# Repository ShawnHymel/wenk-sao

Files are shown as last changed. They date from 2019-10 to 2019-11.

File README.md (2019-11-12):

Wenk SAO
========
Wenk Shitty Add-On to be used as a training tool for the "Microcontrollers the Hard Way" workshop. See Documentation/Worksheet and Documentation/Slides for more information.

Solder connector on bottom to use as a Shitty Add-On for badges. Refer to [Shitty Add-On v1.69bis Standard](https://hackaday.io/project/52950-shitty-add-ons/log/159806-introducing-the-shitty-add-on-v169bis-standard) for more information.

VCC: 3.3-5 V
ATtiny84A@1MHz

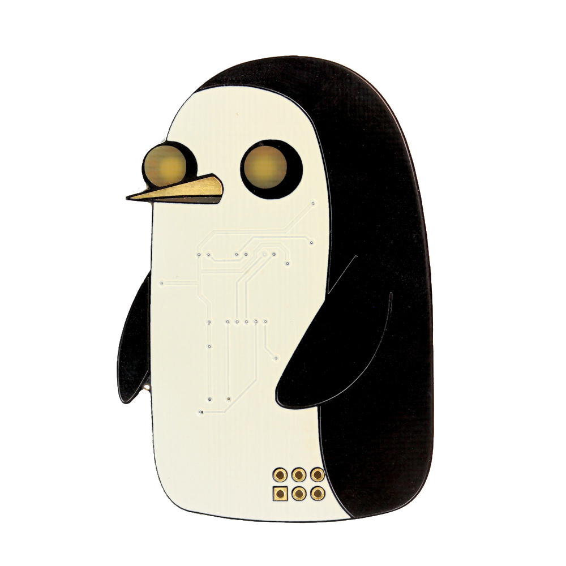
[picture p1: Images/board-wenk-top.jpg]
Wenk Shitty Add-On


Repository Contents
-------------------
* **Documentation** - Slides, worksheet, datasheets
* **Firmware** - Demo programs for the workshop
* **Hardware** - KiCad PCB files, BOM, Gerbers
* **Images** - Photos, diagrams, silkscreen artwork

License
-------
The hardware is released under [Creative Commons Attribution 4.0 International (CC BY 4.0)](https://creativecommons.org/licenses/by/4.0/).

The workshop slides and worksheet are released under [Creative Commons Attribution 4.0 International (CC BY 4.0)](https://creativecommons.org/licenses/by/4.0/).

Demo code in the Firmware directory is [Beerware](https://en.wikipedia.org/wiki/Beerware).

Distributed as-is; no warranty is given.

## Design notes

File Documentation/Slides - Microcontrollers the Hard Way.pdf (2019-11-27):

# Microcontrollers the Hard Way

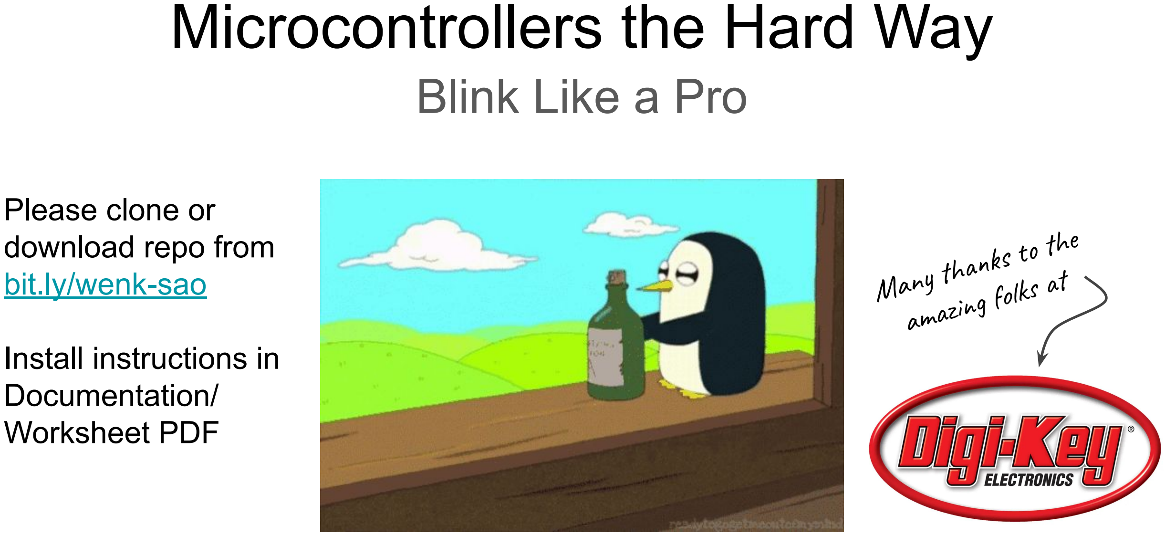
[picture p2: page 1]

# Blink Like a Pro

# Many thanks to the amazing folks at

## Please clone or download repo from bit.ly/wenk-sao

## Install instructions in Documentation/ Worksheet PDF

# Why?

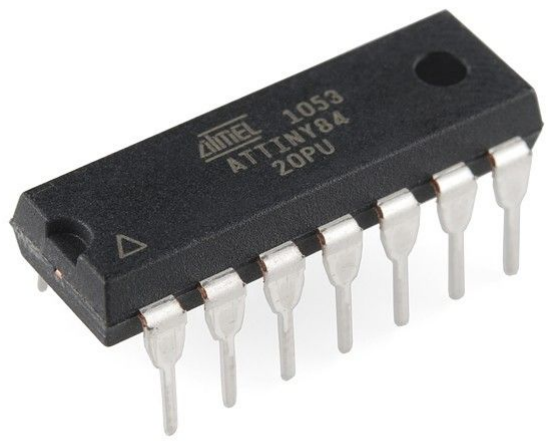
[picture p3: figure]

## - Arduino, Python, MicroPython, CircuitPython are much easier! (Calculator without math) - For product development… - C is usually faster and more space efficient - Need to understand architecture - But AVR is old! 32-bit is the new hotness - Registers - Interrupts - Timers - Peripherals

## Please install AVR toolchain and AVRDUDE while I blab (bit.ly/wenk-sao)

# Hardware Hookup

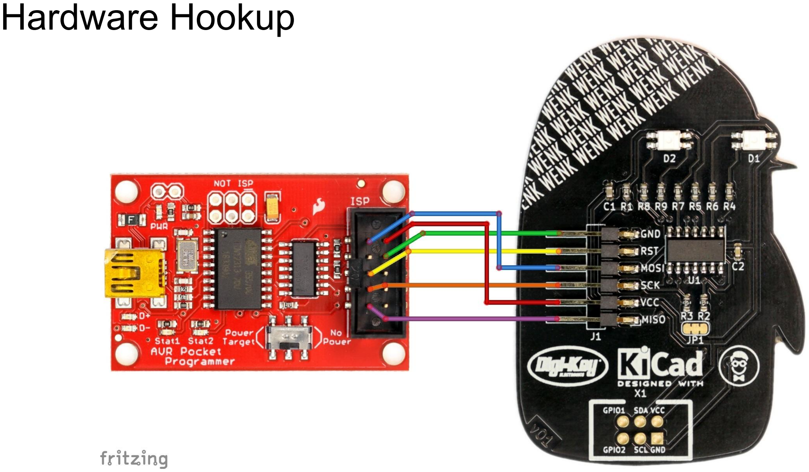
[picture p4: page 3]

# Hints

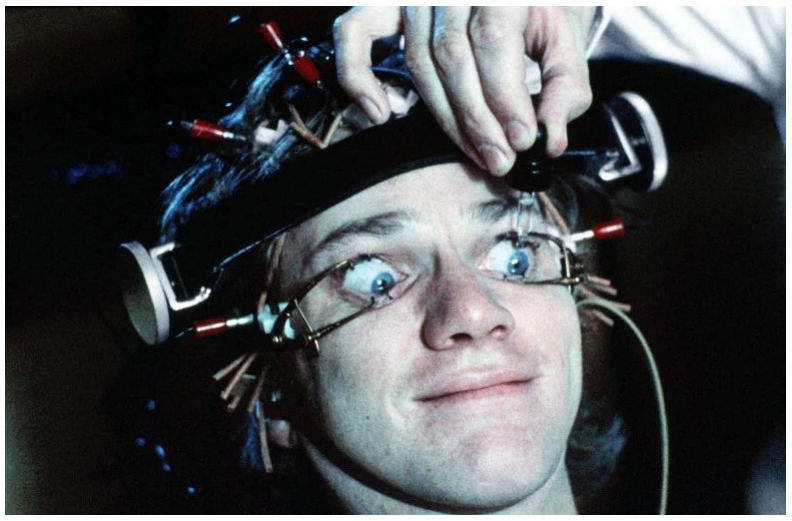
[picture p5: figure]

## - Lots of information ● Type in exercises (at least

## open them from the repo) - Try the challenges ● Have the datasheet open in

## another window

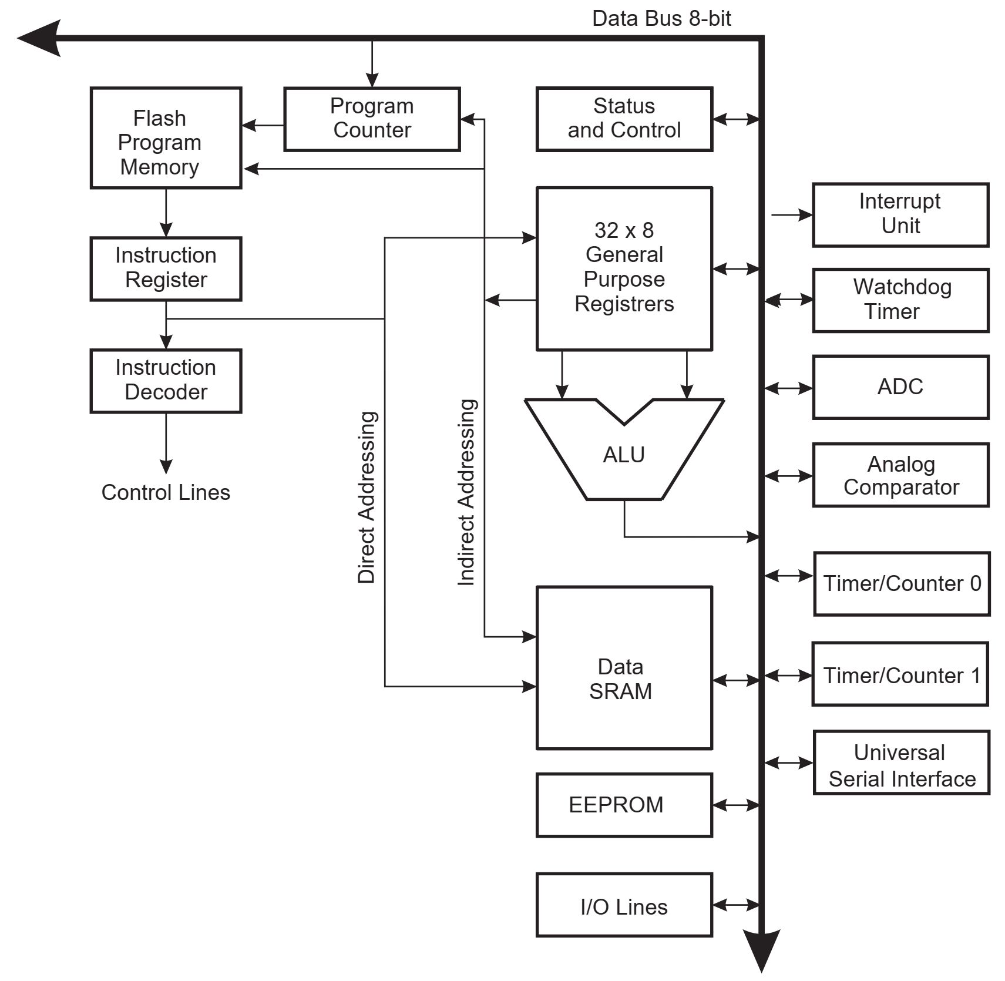
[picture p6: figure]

# ALU

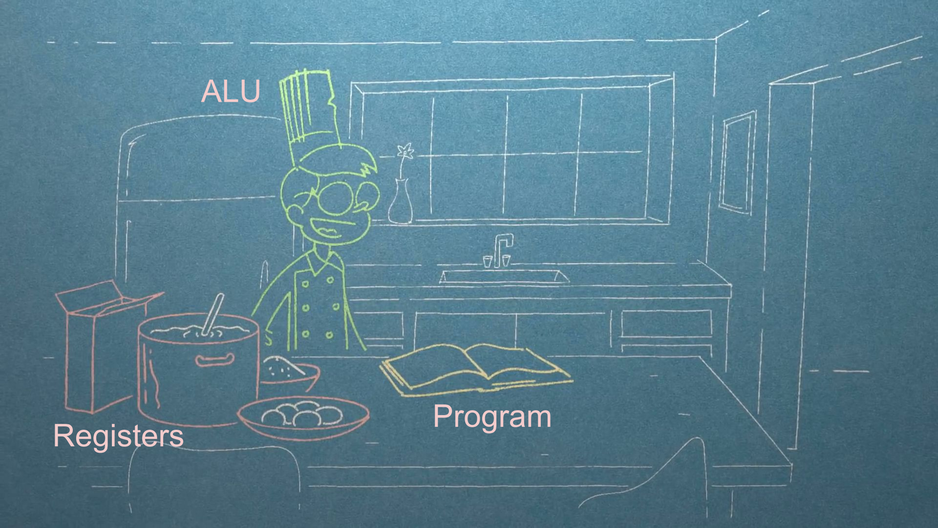
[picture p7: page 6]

Registers | Program

Data Memory

8 bits

32 General
Purpose
Registers

64 I/O Registers

SRAM
(512 x 8 bits)

## Flash (4k x 16 bits)

## Application Flash Section

Program Memory

16 bits

EEPROM

8 bits

EEPROM
(512 x 8 bits)

3 Fuse bytes
1 Lock bytes

Fuses and
Locks
8 bits

Your program lives here

Your variables
live here

Put non-volatile
data here

Danger!
Danger!

## From datasheet

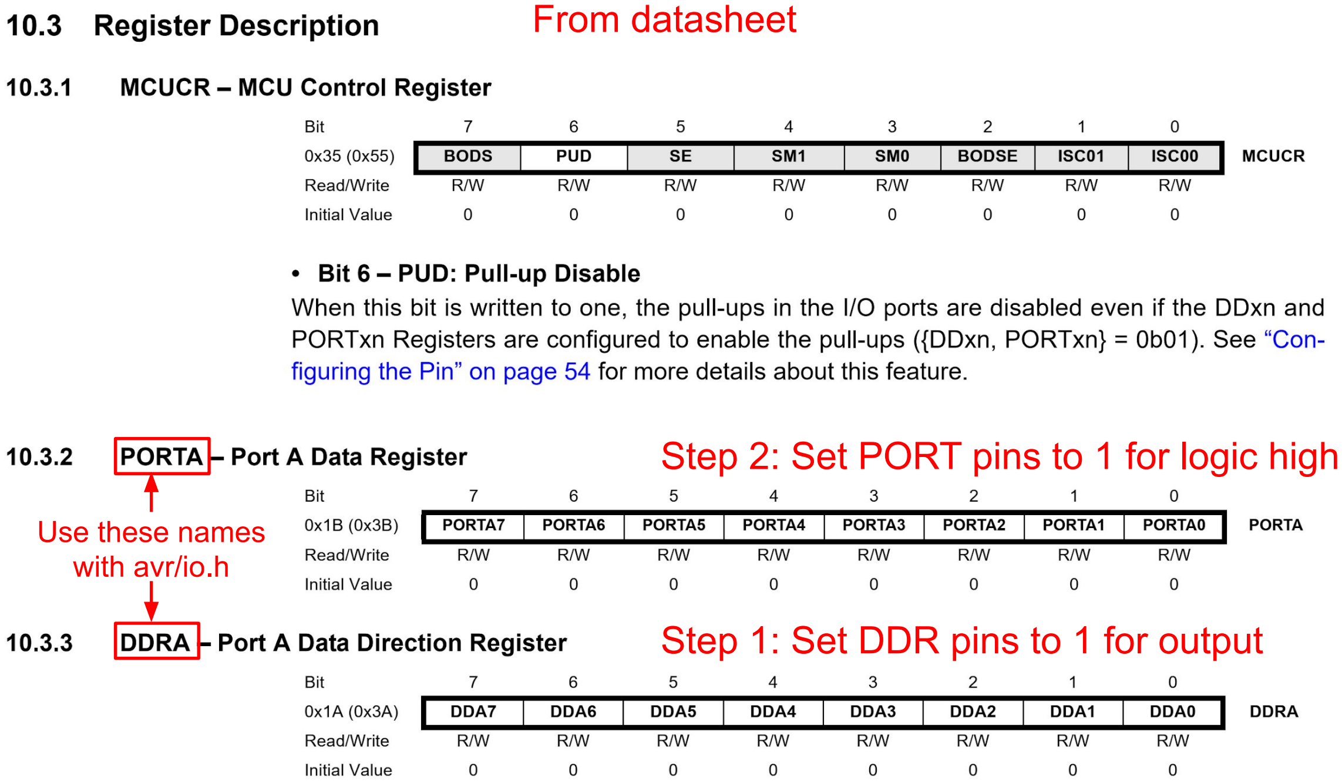
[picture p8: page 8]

## Step 1: Set DDR pins to 1 for output

## Step 2: Set PORT pins to 1 for logic high

Use these names
with avr/io.h

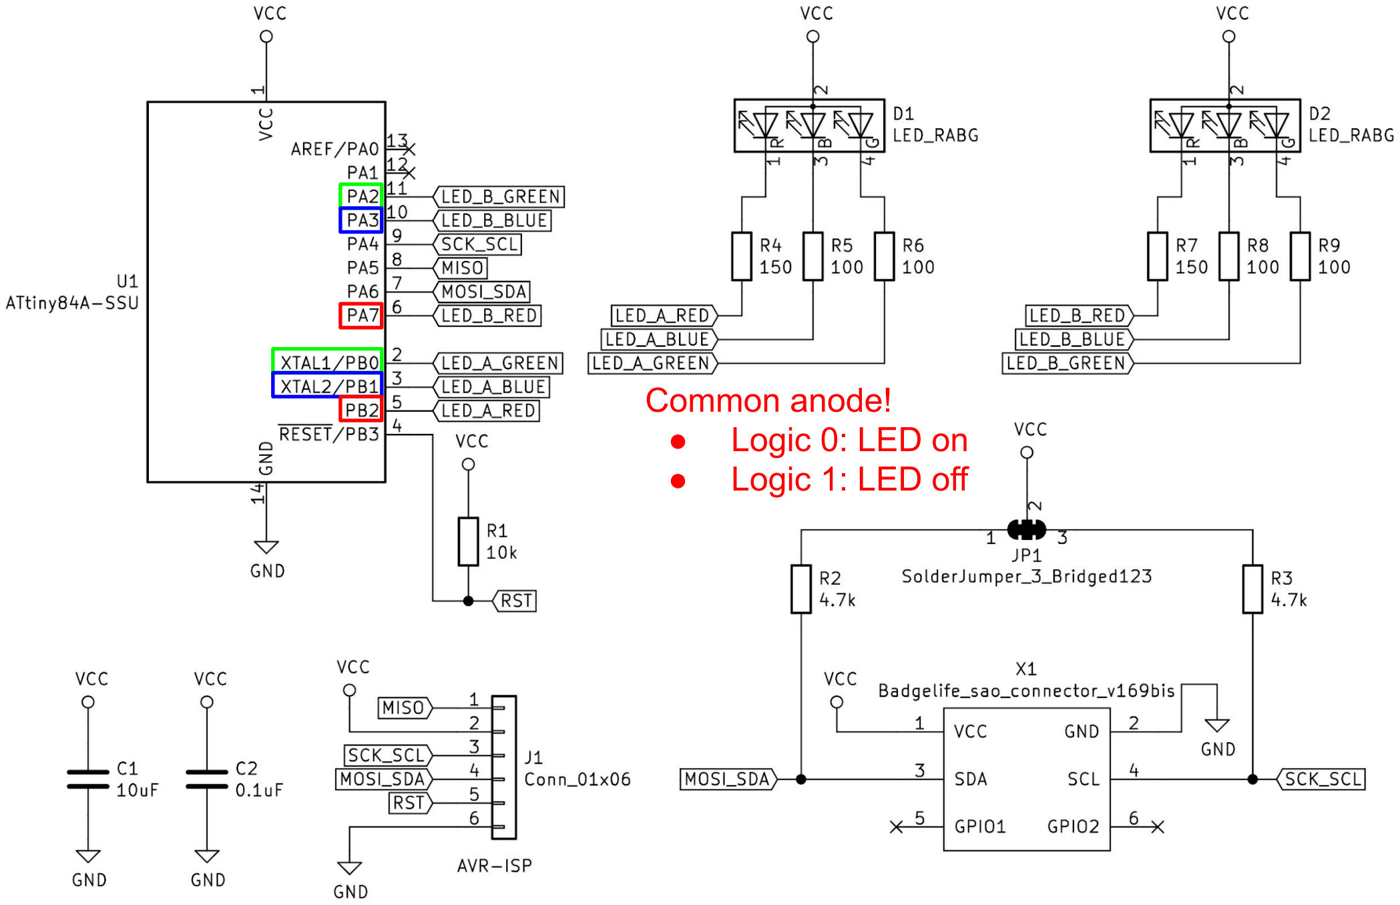
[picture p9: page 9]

Common anode!
- Logic 0: LED on
- Logic 1: LED off

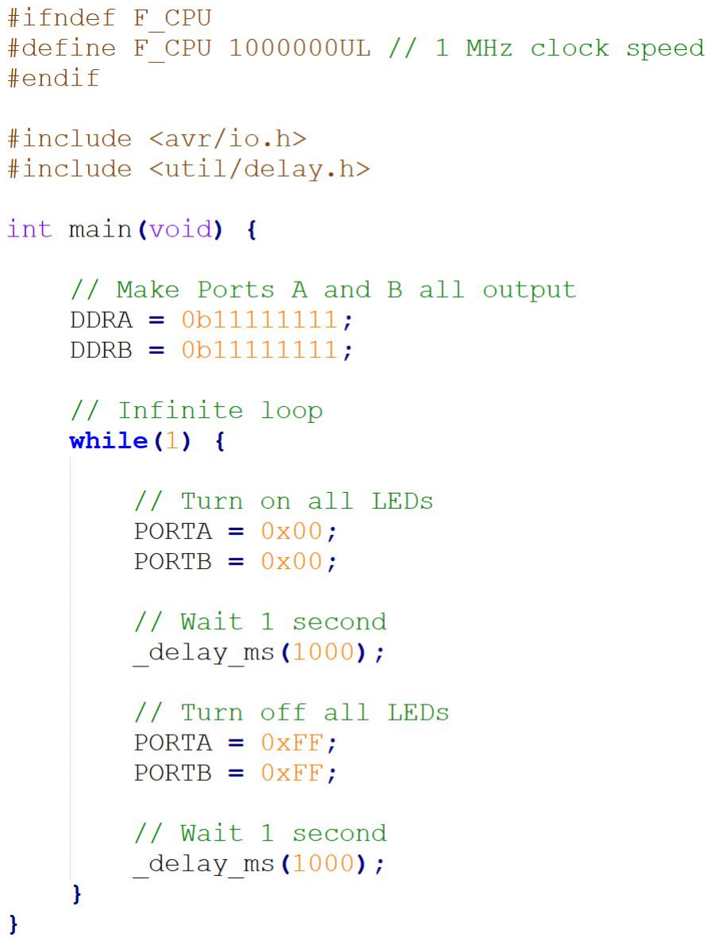
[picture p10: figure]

Exercise 01 - Blinky!

- Create AVR Projects folder somewhere on your computer
- In it, create blinky.c
- In blinky.c, enter the code on the right
- Save
- Open new terminal, enter commands:

avr-gcc -Os -mmcu=attiny84 -o blinky.elf blinky.c avr-objcopy -j .text -j .data -O ihex blinky.elf blinky.hex avrdude -c usbtiny -p t84 -U flash:w:blinky.hex

Or from wenk-sao main directory:

python upload.py <path/to/blinky.c>

Hint: Up arrow is your friend in the terminal to replay commands

Challenge: Only flash the green LED instead of all 3 LEDs

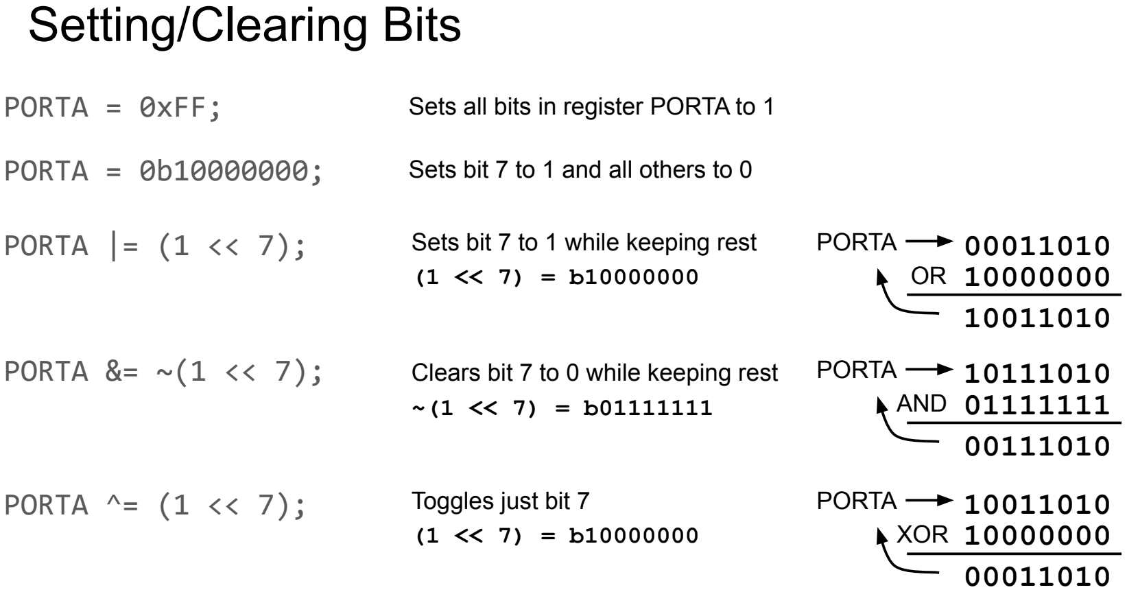
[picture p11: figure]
Setting/Clearing Bits; Sets all bits in register PORTA to 1; Sets bit 7 to 1 and all others to 0; PORTA; Sets bit 7 to 1 while keeping rest; AND 01111111; Clears bit 7 to 0 while keeping rest; XOR 10000000; Toggles just bit 7; PORTA = 0b10000000;; PORTA |= (1 << 7);; PORTA &= ~(1 << 7);; PORTA ^= (1 << 7);; PORTA = 0xFF;

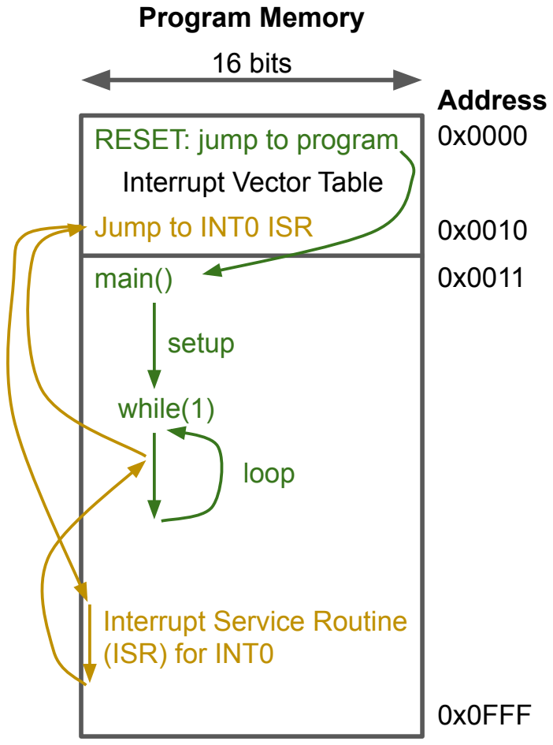
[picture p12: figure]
Program Memory; 16 bits; 0x0FFF; Address; Interrupt Vector Table; RESET: jump to program; main(); while(1); setup; loop; Jump to INT0 ISR; Interrupt Service Routine (ISR) for INT0

# Intro to Interrupts

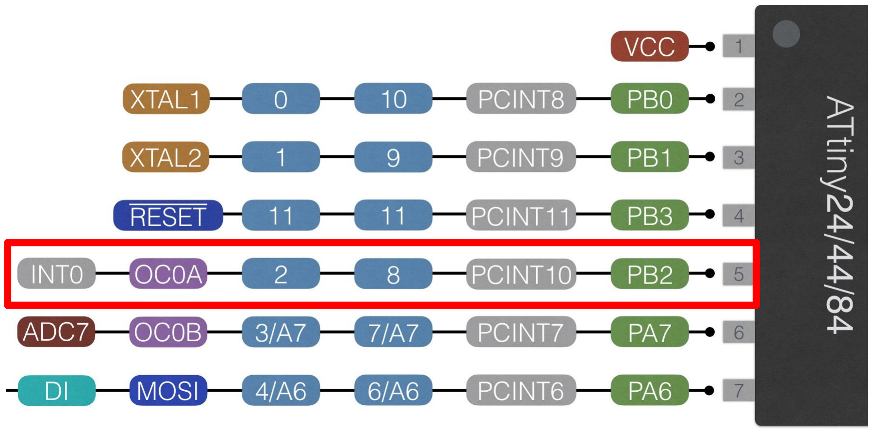
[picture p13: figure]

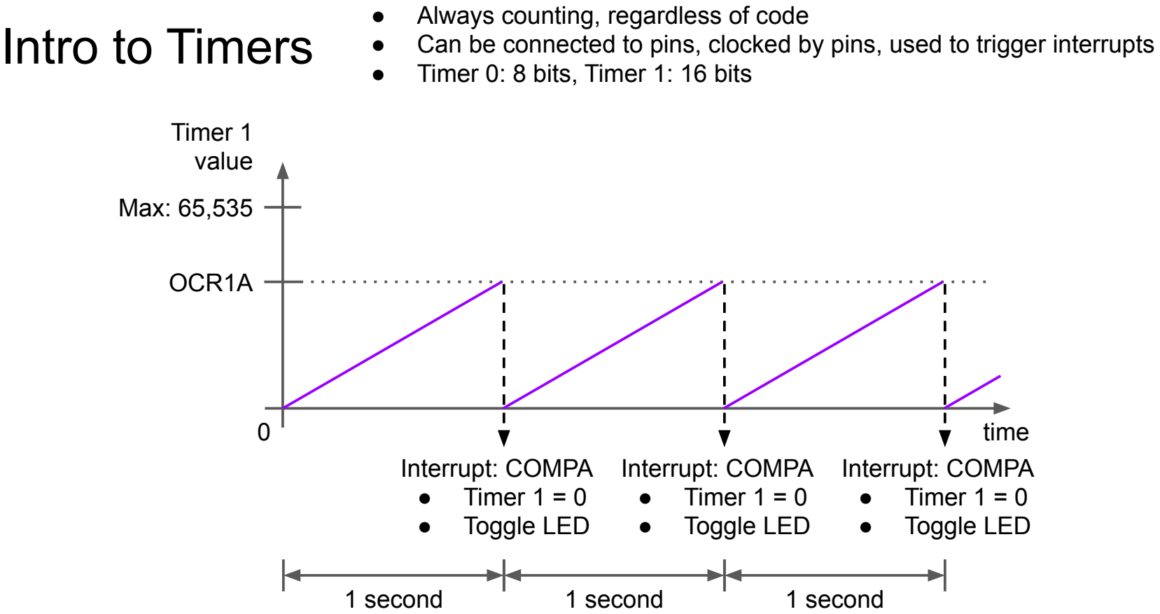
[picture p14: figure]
Intro to Timers; Timer 1 value; Max: 65,535; ● Always counting, regardless of code; ● Timer 0: 8 bits, Timer 1: 16 bits; OCR1A; time; Interrupt: COMPA ● Timer 1 = 0 ● Toggle LED; 1 second

- Can be connected to pins, clocked by pins, used to trigger interrupts

# Timer Calculations

## Period:

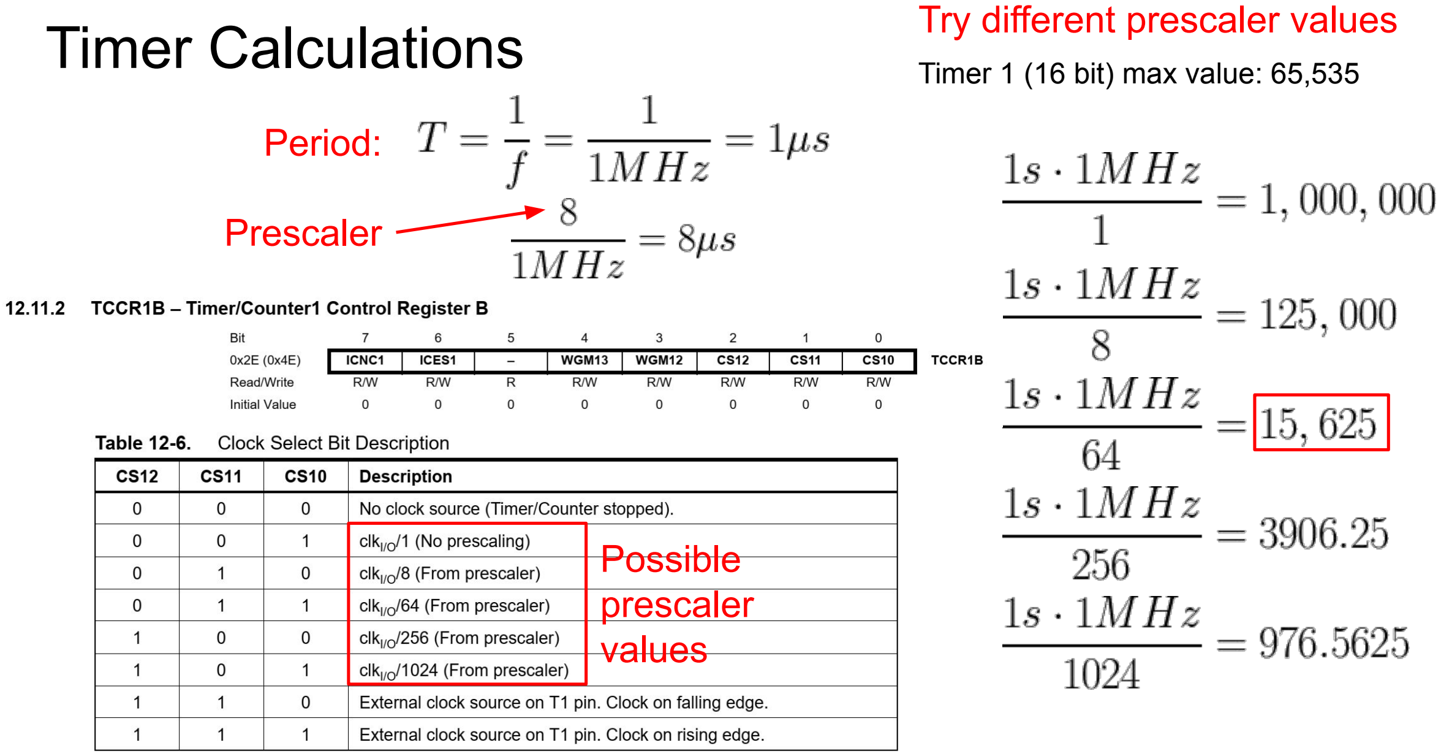
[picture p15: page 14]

## Prescaler

## Possible prescaler values

## Try different prescaler values

Timer 1 (16 bit) max value: 65,535

# How to Set Up Timer 1

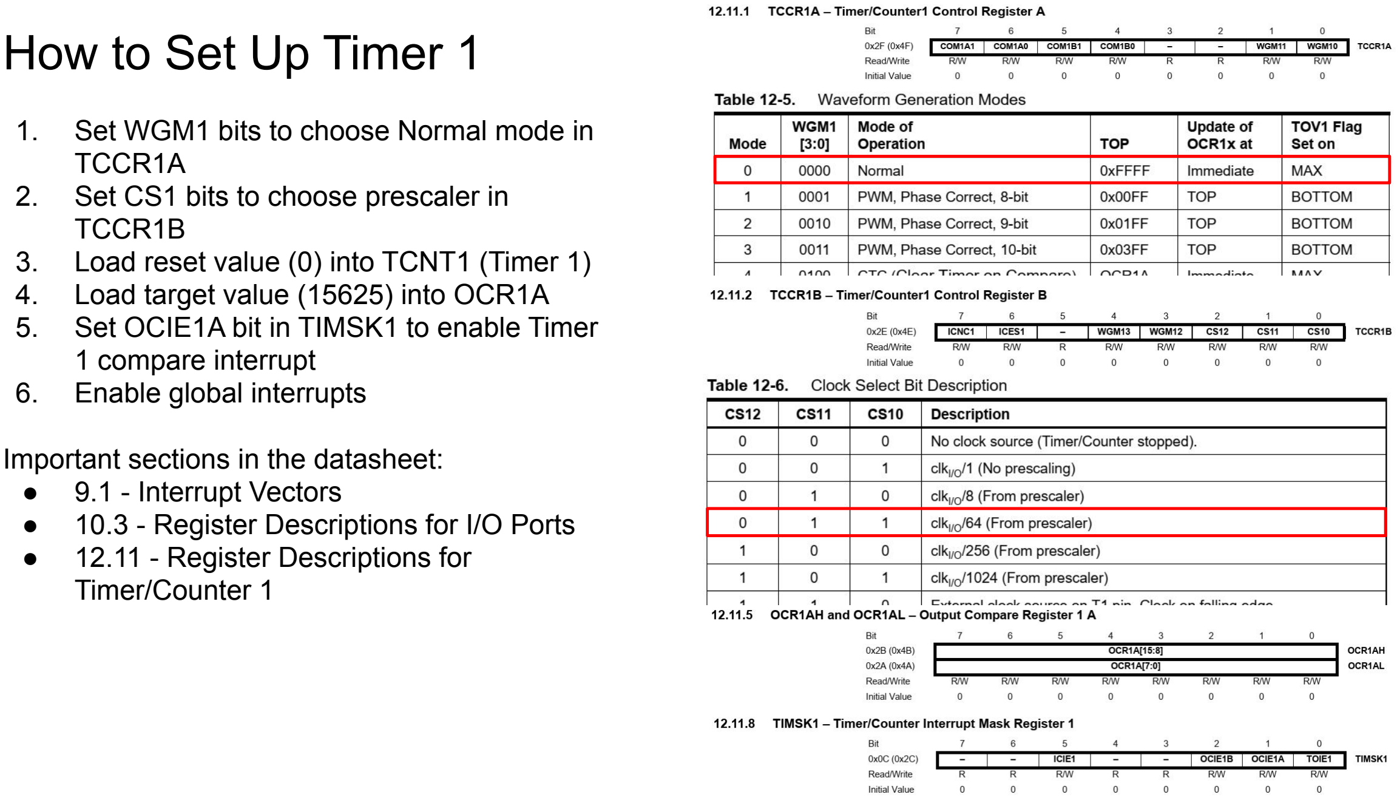
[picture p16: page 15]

1. Set WGM1 bits to choose Normal mode in TCCR1A
2. Set CS1 bits to choose prescaler in TCCR1B
3. Load reset value (0) into TCNT1 (Timer 1)
4. Load target value (15625) into OCR1A
5. Set OCIE1A bit in TIMSK1 to enable Timer 1 compare interrupt
6. Enable global interrupts

Important sections in the datasheet:
- 9.1 - Interrupt Vectors
- 10.3 - Register Descriptions for I/O Ports
- 12.11 - Register Descriptions for Timer/Counter 1

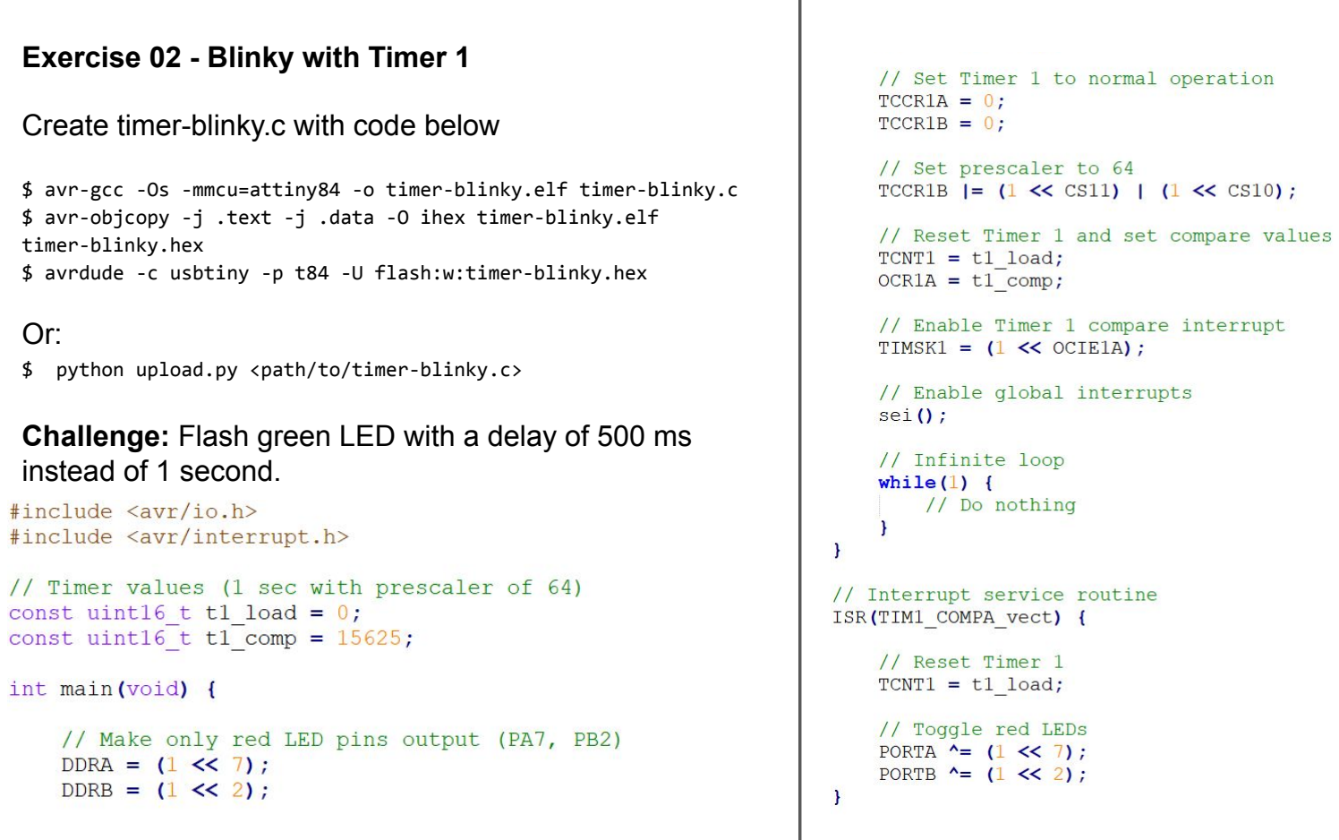
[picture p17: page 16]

Exercise 02 - Blinky with Timer 1

Create timer-blinky.c with code below

$ avr-gcc -Os -mmcu=attiny84 -o timer-blinky.elf timer-blinky.c $ avr-objcopy -j .text -j .data -O ihex timer-blinky.elf timer-blinky.hex
$ avrdude -c usbtiny -p t84 -U flash:w:timer-blinky.hex

Or:

$ python upload.py <path/to/timer-blinky.c>

Challenge: Flash green LED with a delay of 500 ms instead of 1 second.

# Intro to Pulse Width Modulation

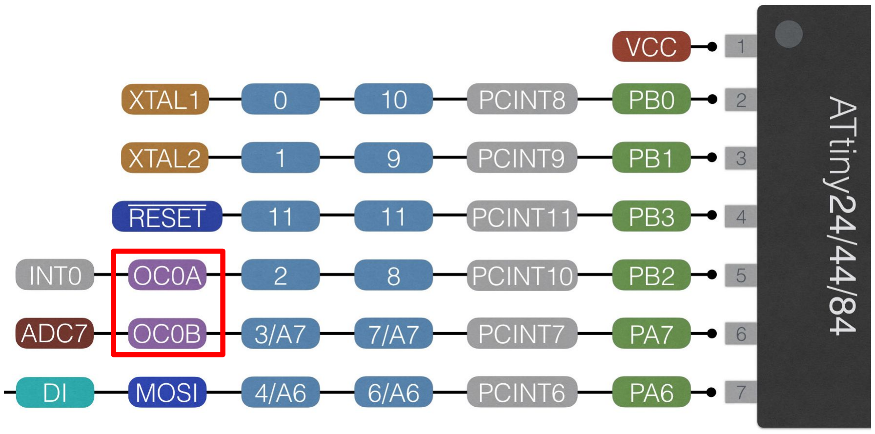
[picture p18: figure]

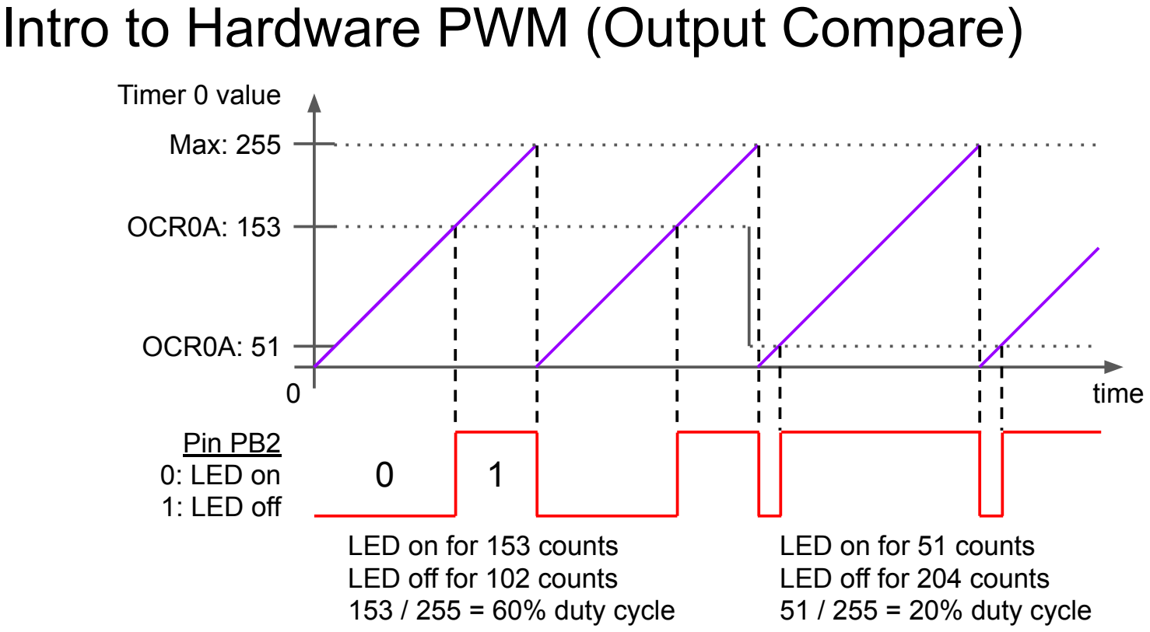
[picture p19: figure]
Intro to Hardware PWM (Output Compare); Timer 0 value; Max: 255; OCR0A: 153; time; Pin PB2 0: LED on 1: LED off; LED on for 153 counts LED off for 102 counts 153 / 255 = 60% duty cycle; OCR0A: 51; LED on for 51 counts LED off for 204 counts 51 / 255 = 20% duty cycle

# How to Set Up PWM

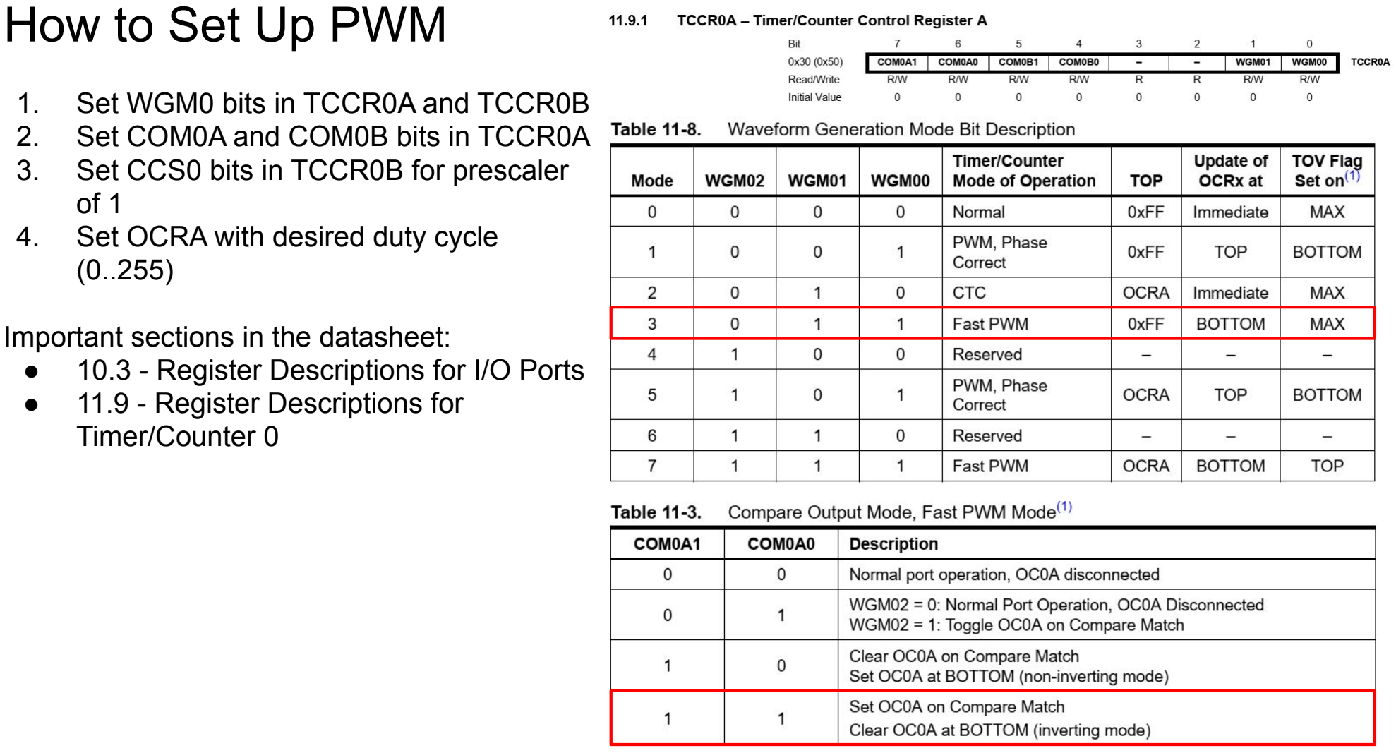
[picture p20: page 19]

1. Set WGM0 bits in TCCR0A and TCCR0B
2. Set COM0A and COM0B bits in TCCR0A
3. Set CCS0 bits in TCCR0B for prescaler of 1
4. Set OCRA with desired duty cycle (0..255)

Important sections in the datasheet:
- 10.3 - Register Descriptions for I/O Ports
- 11.9 - Register Descriptions for Timer/Counter 0

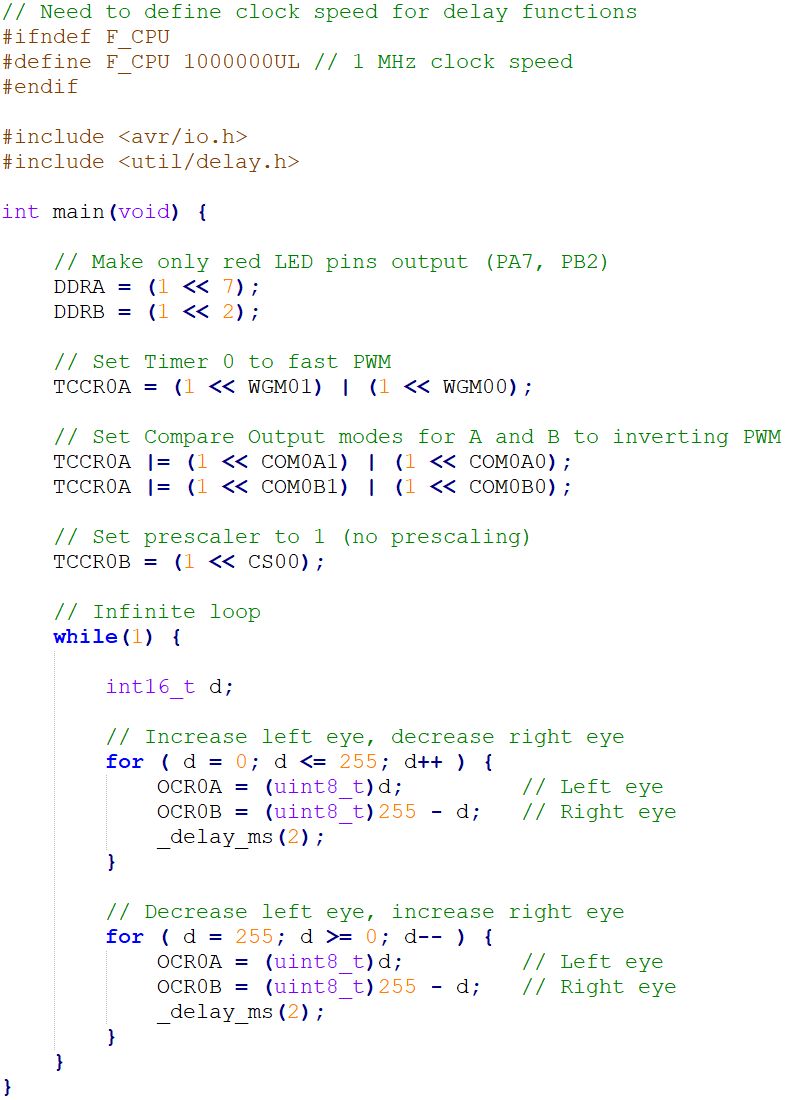
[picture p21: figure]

Exercise 03 - Hardware PWM

Create hardware-pwm.c with code to the right

$ avr-gcc -Os -mmcu=attiny84 -o hardware-pwm.elf hardware-pwm.c $ avr-objcopy -j .text -j .data -O ihex hardware-pwm.elf hardware-pwm.hex
$ avrdude -c usbtiny -p t84 -U flash:w:hardware-pwm.hex

Or:

$ python upload.py <path/to/hardware-pwm.c>

Challenge: Notice that a duty cycle of 0% does not completely turn off LED. This is because in Fast PWM mode, at least 1 clock cycle happens while pin is low (LED on). Fix this by using Phase Correct PWM.

Hint: Read about the WGM0 bits in the TCCR0A register (datasheet section 11.9.1)

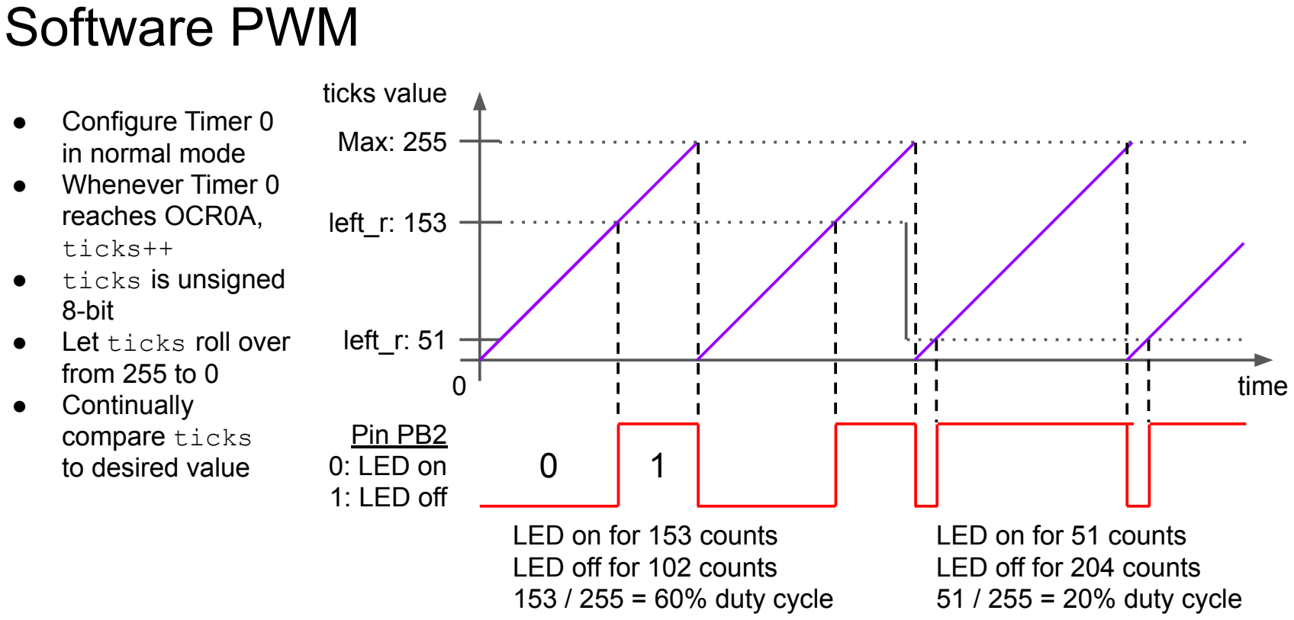
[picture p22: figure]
Software PWM; ticks value; Max: 255; left_r: 153; time; Pin PB2 0: LED on 1: LED off; LED on for 153 counts LED off for 102 counts 153 / 255 = 60% duty cycle; left_r: 51; LED on for 51 counts LED off for 204 counts 51 / 255 = 20% duty cycle; ● Configure Timer 0 in normal mode ● Whenever Timer 0 reaches OCR0A,; ticks++ ● ticks is unsigned 8-bit ● Let ticks roll over from 255 to 0 ● Continually compare ticks to desired value

# PWM Frequency

## CPU clock: 1 MHz

## Timer 0 prescaler: 1

## OCR0A (comp): ???

## Ticks counting from 0 to 255 is one period

## 50 Hz LED refresh looks decent (and it’s the best we can do)

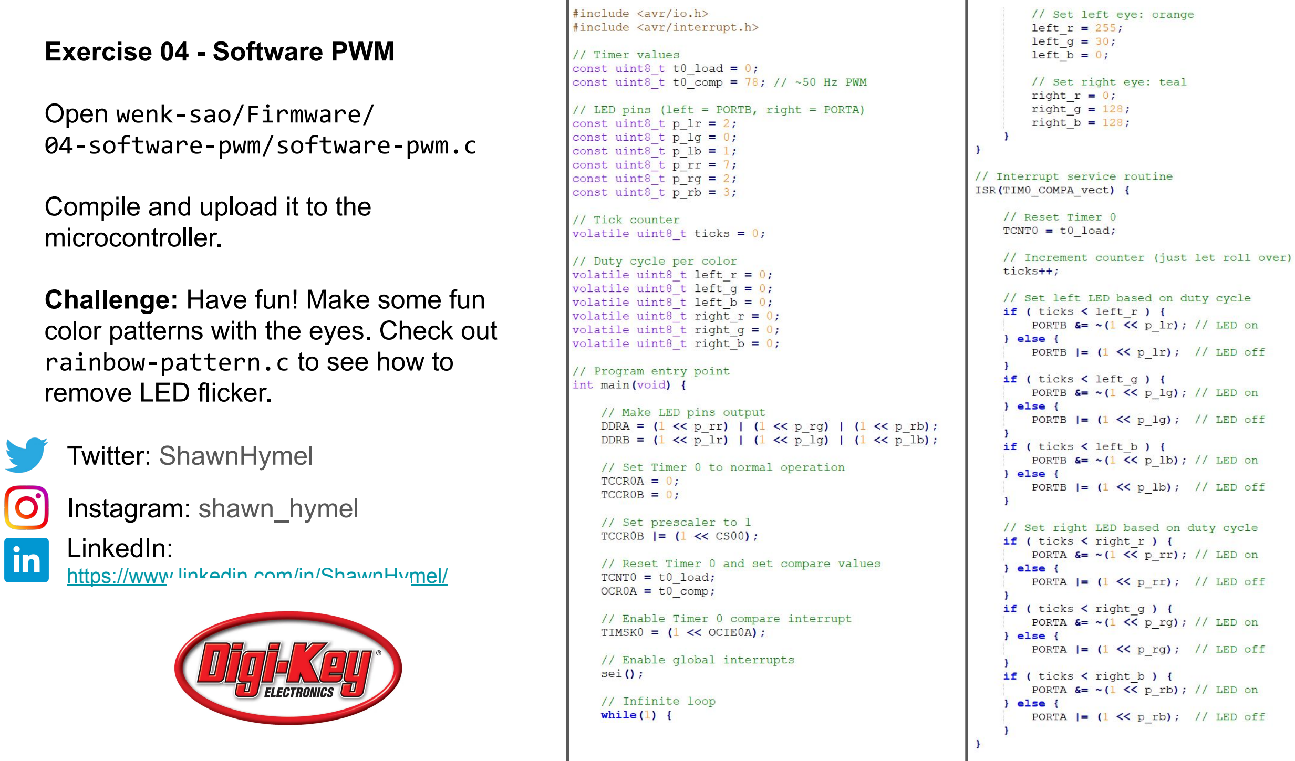
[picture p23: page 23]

Exercise 04 - Software PWM

Open wenk-sao/Firmware/
04-software-pwm/software-pwm.c

Compile and upload it to the microcontroller.

Challenge: Have fun! Make some fun color patterns with the eyes. Check out rainbow-pattern.c to see how to remove LED flicker.

Twitter: ShawnHymel

Instagram: shawn_hymel
LinkedIn:
https://www.linkedin.com/in/ShawnHymel/

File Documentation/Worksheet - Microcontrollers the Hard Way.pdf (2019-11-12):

## Microcontrollers the Hard Way

Worksheet by Shawn Hymel (License: CC BY 4.0) Presented by DigiKey Electronics

Name:______________________ Date:_______________________

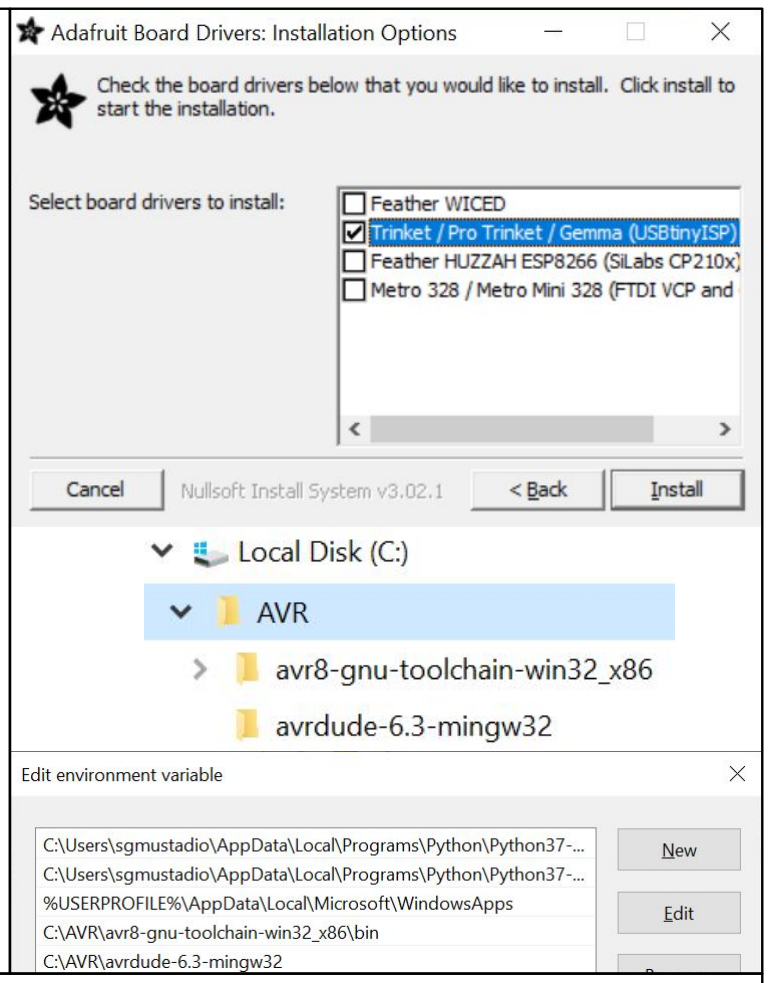
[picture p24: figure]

Installation (Windows)
- Install driver: bit.ly/adafruit-drivers-install
- Select Trinket…(USBtinyISP)
- Now plug in AVR Programmer
- Create folder C:\AVR
- Download AVR 8-bit Toolchain for Windows (v3.62) from: bit.ly/avr-toolchain-install
- Unzip into C:\AVR
- Download avrdude-6.3-mingw32.zip from: http://bit.ly/avrdude-install
- Unzip into C:\AVR\avrdude-6.3-mingw32
- Update Path
- Control Panel > System and Security > System > Advanced System Settings > Advanced tab > Environment Variables
- User Variables, select Path, click Edit
- Click New, Click Browse…, add C:\AVR\avr8-gnu-toolchain-win32_x86\bin
- Click New, Click Browse…, add C:\AVR\avrdude-6.3-mingw32

Toolchain Setup

Installation (Mac)
- Install Homebrew:
$ ruby -e "$(curl -fsSL https://raw.githubusercontent.com/Homebrew/install/master/install)"
- Install AVR toolchain:
$ brew tap osx-cross/avr
$ brew install avr-gcc
- Install avrdude:
$ brew install avrdude

Installation (Linux)
- Install AVR toolchain and avrdude:
$ sudo apt update
$ sudo apt install -y gcc-avr binutils-avr avr-libc avrdude
- Download ZIP from github.com/ShawnHymel/wenk-sao
- Unzip somewhere on your computer

Project Files

- In a terminal, enter $ avr-gcc
- You should see an error: avr-gcc: fatal error: no input files
- Next, enter $ avrdude
- You should see an error: Usage: avrdude [options]

Test It!

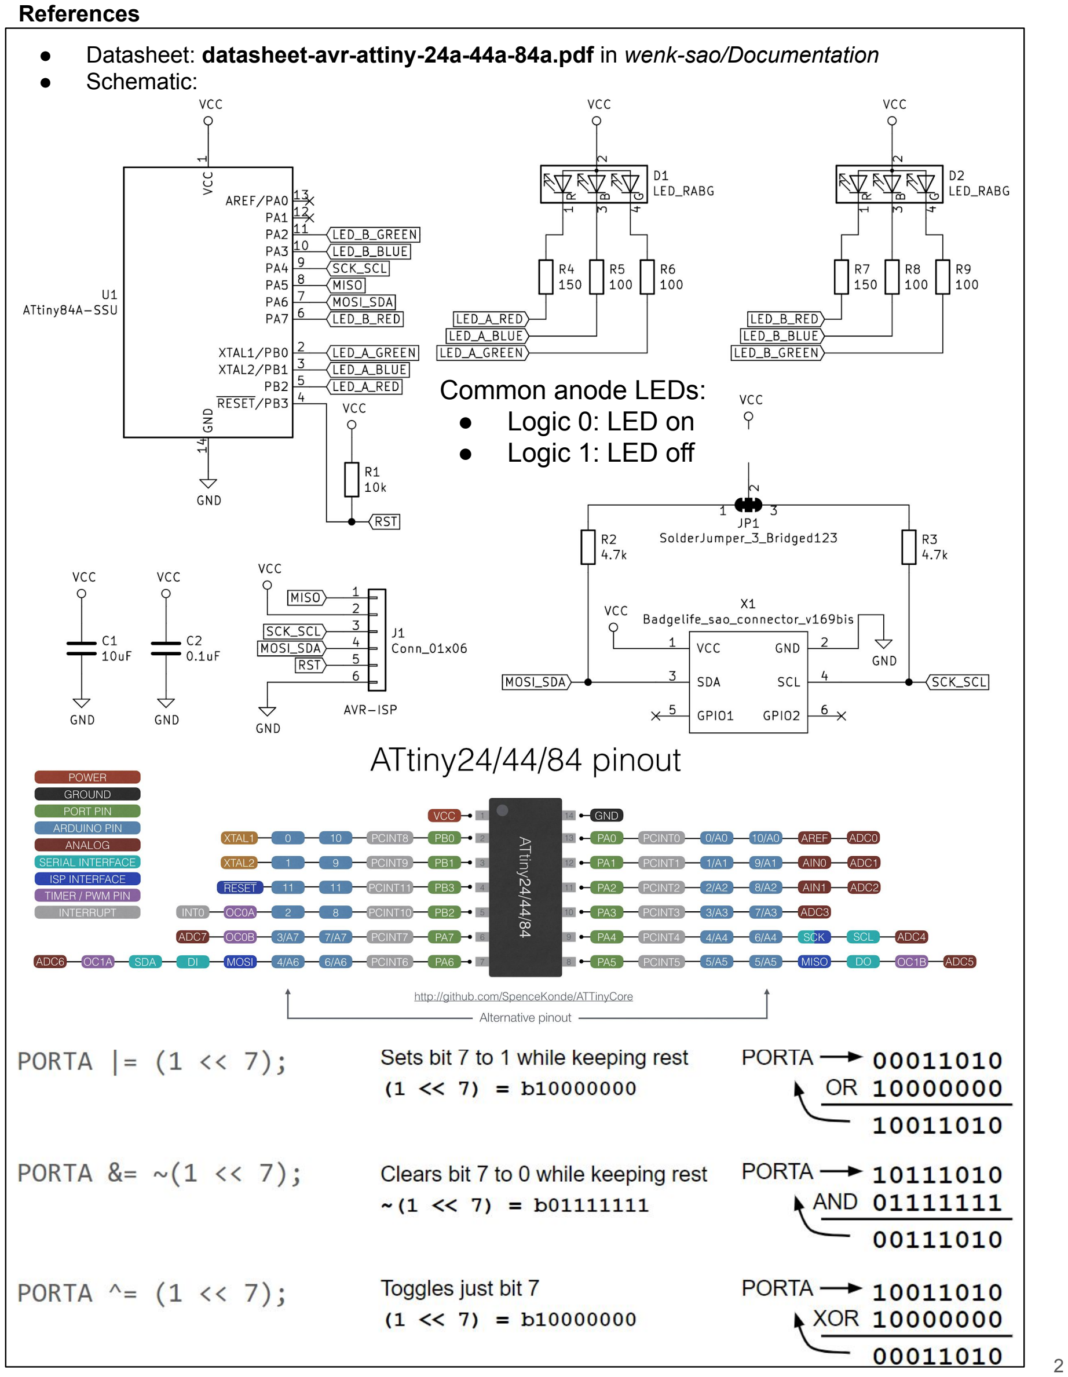
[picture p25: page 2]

- Datasheet: datasheet-avr-attiny-24a-44a-84a.pdf in wenk-sao/Documentation
- Schematic:

References

Common anode LEDs:
- Logic 0: LED on
- Logic 1: LED off


Hardware Connections

Exercise 01 - Blinky!


Compile and Upload
Open new terminal, enter commands:
$ cd <location of your AVR Projects directory>
$ avr-gcc -Os -mmcu=attiny84 -o blinky.elf blinky.c
$ avr-objcopy -j .text -j .data -O ihex blinky.elf blinky.hex $ avrdude -c usbtiny -p t84 -U flash:w:blinky.hex

Or if you have Python (from wenk-sao directory):
$ python upload.py <path/to/blinky.c>

Hint: up arrow is your friend in the terminal to replay commands

Challenge: Flash only the green LED instead of all 3 LEDs

Write Code
- Create AVR Projects folder somewhere on your computer
- In it, create blinky.c
- Open blinky.c with your favorite editor (not WordPad)
- In blinky.c, enter the code on the right
- Save

Exercise 02 - Blinky with Timer 1

Compile and Upload


$ avr-gcc -Os -mmcu=attiny84 -o timer-blinky.elf timer-blinky.c
$ avr-objcopy -j .text -j .data -O ihex timer-blinky.elf timer-blinky.hex $ avrdude -c usbtiny -p t84 -U flash:w:timer-blinky.hex

Or if you have Python (from wenk-sao directory):
$ python upload.py <path/to/timer-blinky.c>

Challenge: Flash green LED with a delay of 500 ms instead of 1 second.

Write Code
- Create timer-blinky.c
- Open timer-blinky.c with your favorite editor (not WordPad)
- In timer-blinky.c, enter the code on the right
- Save

Important Datasheet Sections
- 9.1 - Interrupt Vectors
- 10.3 - Register Descriptions for I/O Ports
- 12.11 - Register Descriptions for Timer/Counter 1

Exercise 03 - Hardware PWM

Compile and Upload


$ avr-gcc -Os -mmcu=attiny84 -o hardware-pwm.elf hardware-pwm.c
$ avr-objcopy -j .text -j .data -O ihex hardware-pwm.elf hardware-pwm.hex $ avrdude -c usbtiny -p t84 -U flash:w:hardware-pwm.hex

Or if you have Python (from wenk-sao directory):
$ python upload.py <path/to/hardware-pwm.c>

Challenge: Notice that a duty cycle of 0% does not completely turn off LED. This is because in Fast PWM mode, at least 1 clock cycle happens while pin is low (LED on). Fix this by using Phase Correct PWM.

Hint: Read about the WGM0 bits in the TCCR0A register (datasheet section 11.9.1)

Write Code
- Create hardware-pwm.c
- Open hardware-pwm.c with your favorite editor (not WordPad)
- In hardware-pwm.c, enter the code on the right
- Save

Important Datasheet Sections
- 10.3 - Register Descriptions for I/O Ports
- 11.9 - Register Descriptions for Timer/Counter 0

Exercise 04 - Software PWM

This is more for fun! Open wenk-sao/Firmware/04-software-pwm/software-pwm.c and play around with it.

Compile and Upload
$ avr-gcc -Os -mmcu=attiny84 -o software-pwm.elf software-pwm.c
$ avr-objcopy -j .text -j .data -O ihex software-pwm.elf software-pwm.hex $ avrdude -c usbtiny -p t84 -U flash:w:software-pwm.hex

Or if you have Python (from wenk-sao directory):
$ python upload.py <path/to/software-pwm.c>

Challenge: Make some fun color patterns with the eyes. Check out rainbow-pattern.c to see how to remove LED flicker.

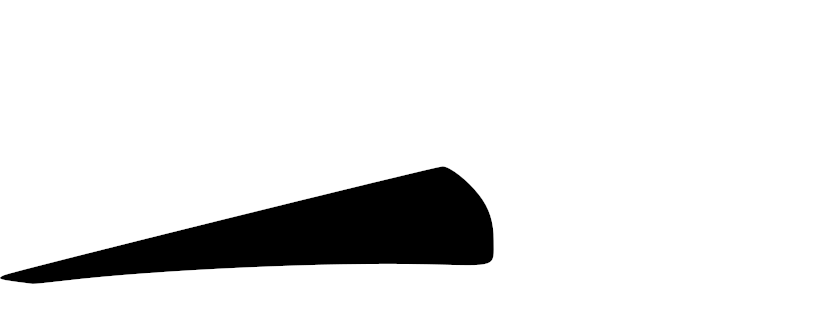
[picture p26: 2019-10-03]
Images/gunter-exposed_copper.png

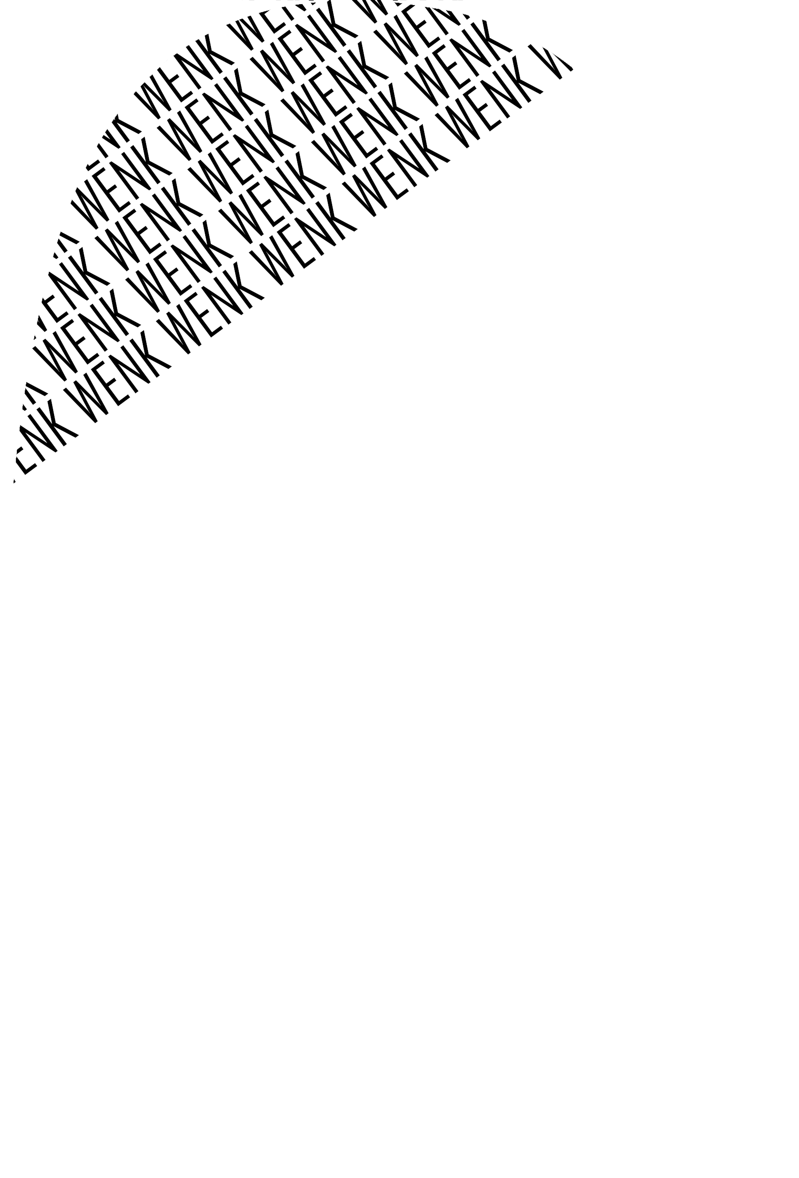
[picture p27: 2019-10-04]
Images/gunter-back_silk.png

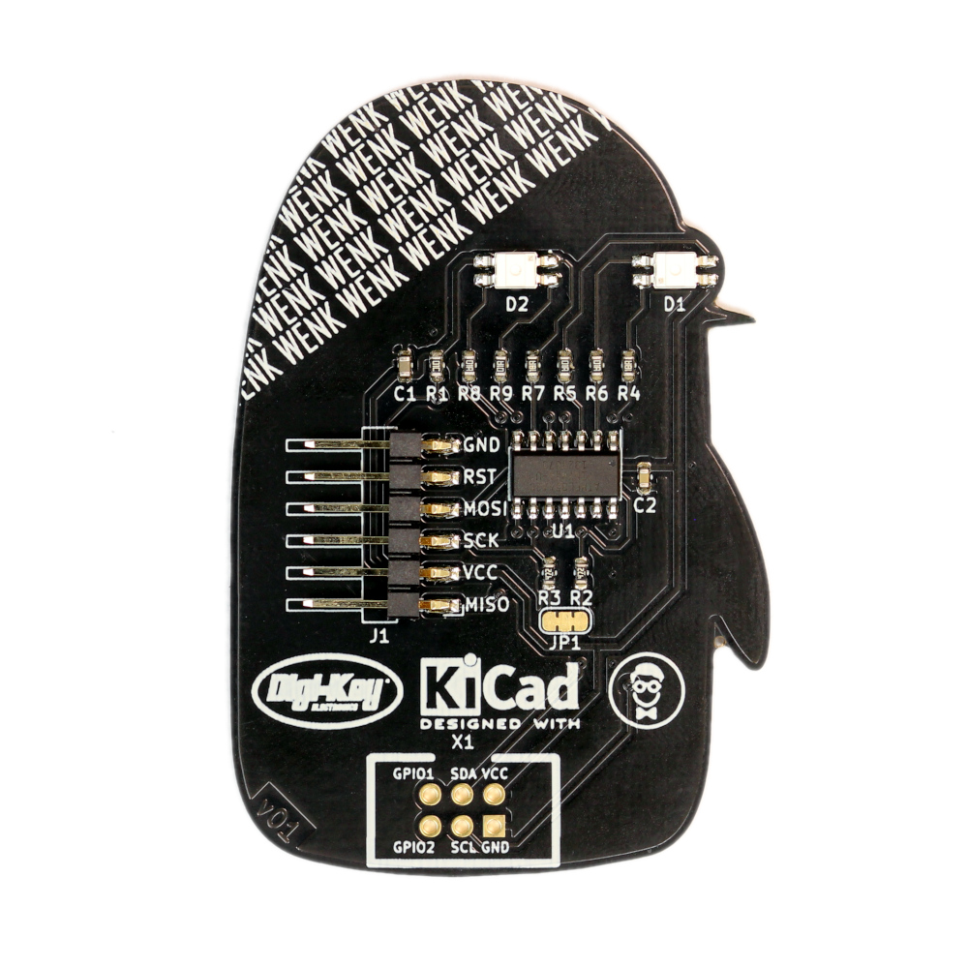
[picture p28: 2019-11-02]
Images/board-wenk-bottom.jpg

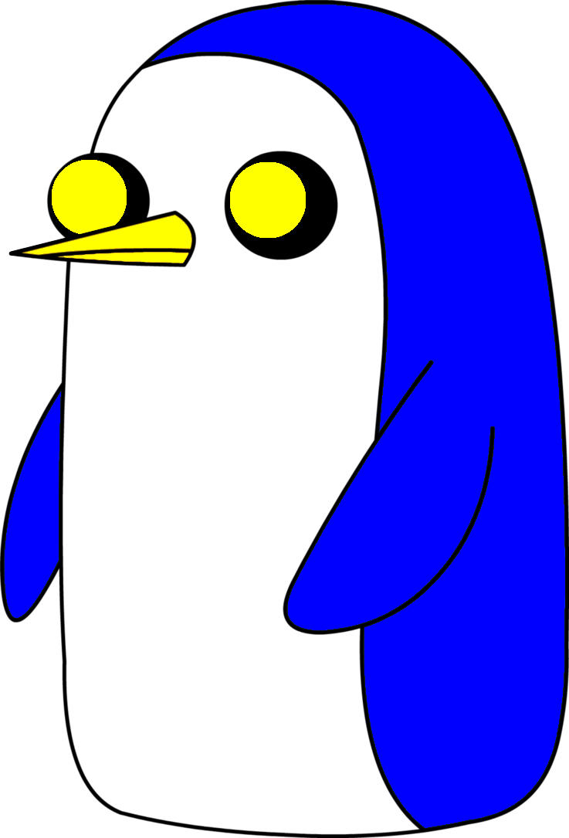
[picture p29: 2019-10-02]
Images/gunter-layers.png

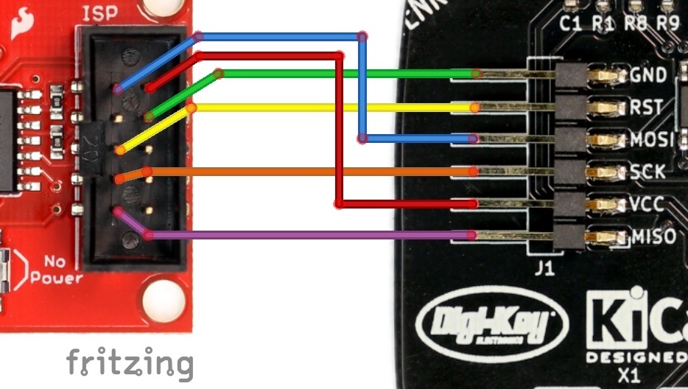
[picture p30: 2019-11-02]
Images/programmer-hookup_bb_cropped.jpg

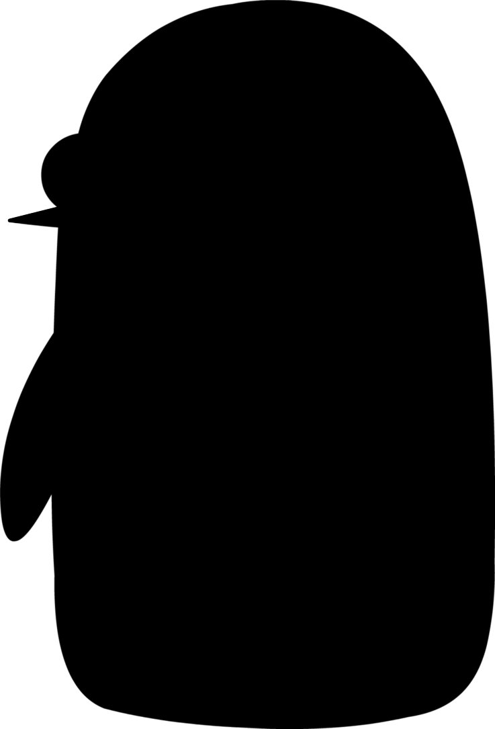
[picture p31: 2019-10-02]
Images/gunter-black.png

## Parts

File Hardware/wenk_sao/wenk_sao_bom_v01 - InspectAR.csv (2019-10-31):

Component | Description | Part | RefDes | Value | Footprint | Quantity Per PCB | Datasheet | MPN
1 | Unpolarized capacitor | C | C2 | 0.1uF | C_0603_1608Metric | 1 | ~ | 1276-1000-1-ND
2 | Unpolarized capacitor | C | C1 | 10uF | C_0603_1608Metric | 1 | ~ | 1276-1119-1-ND
3 | RGB LED, anode/red/green/blue | LED_RABG | D1 D2 | LED_RABG | XZMDKCBDDG45S-9 | 2 | ~ | 1497-1257-1-ND
4 | Generic connector, single row, 01x06, script generated (kicad-library-utils/schlib/autogen/connector/) | Conn_01x06 | J1 | Conn_01x06 | Harwin_M20-89006xx_1x06_P2.54mm_Horizontal | 1 | ~ | 952-3235-ND
5 | Resistor | R | R5 R6 R8 R9 | 100 | R_0603_1608Metric | 4 | ~ | 311-100HRCT-ND
6 | Resistor | R | R1 | 10k | R_0603_1608Metric | 1 | ~ | 311-10.0KHRCT-ND
7 | Resistor | R | R4 R7 | 150 | R_0603_1608Metric | 2 | ~ | 311-150HRCT-ND
8 | Resistor | R | R2 R3 | 4.7k | R_0603_1608Metric | 2 | ~ | 311-4.70KHRCT-ND
9 | 20MHz, 8kB Flash, 512B SRAM, 512B EEPROM, debugWIRE, SOIC-14 | ATtiny84A-SSU | U1 | ATtiny84A-SSU | SOIC-14_3.9x8.7mm_P1.27mm | 1 | http://ww1.microchip.com/downloads/en/DeviceDoc/doc8183.pdf | ATTINY84A-SSURCT-ND
10 |  | Badgelife_sao_connector_v169bis | X1 | Badgelife_sao_connector_v169bis | Badgelife-SAOv169-SAO-2x3_nopin1 | 1 |  | 732-5394-ND

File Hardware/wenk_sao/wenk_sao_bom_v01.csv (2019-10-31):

Component | Description | Part | References | Value | Footprint | Quantity Per PCB | Datasheet | Digi-Key_PN
1 | Unpolarized capacitor | C | C2 | 0.1uF | C_0603_1608Metric | 1 | ~ | 1276-1000-1-ND
2 | Unpolarized capacitor | C | C1 | 10uF | C_0603_1608Metric | 1 | ~ | 1276-1119-1-ND
3 | RGB LED, anode/red/green/blue | LED_RABG | D1 D2 | LED_RABG | XZMDKCBDDG45S-9 | 2 | ~ | 1497-1257-1-ND
4 | Generic connector, single row, 01x06, script generated (kicad-library-utils/schlib/autogen/connector/) | Conn_01x06 | J1 | Conn_01x06 | Harwin_M20-89006xx_1x06_P2.54mm_Horizontal | 1 | ~ | 952-3235-ND
5 | Resistor | R | R5 R6 R8 R9 | 100 | R_0603_1608Metric | 4 | ~ | 311-100HRCT-ND
6 | Resistor | R | R1 | 10k | R_0603_1608Metric | 1 | ~ | 311-10.0KHRCT-ND
7 | Resistor | R | R4 R7 | 150 | R_0603_1608Metric | 2 | ~ | 311-150HRCT-ND
8 | Resistor | R | R2 R3 | 4.7k | R_0603_1608Metric | 2 | ~ | 311-4.70KHRCT-ND
9 | 20MHz, 8kB Flash, 512B SRAM, 512B EEPROM, debugWIRE, SOIC-14 | ATtiny84A-SSU | U1 | ATtiny84A-SSU | SOIC-14_3.9x8.7mm_P1.27mm | 1 | http://ww1.microchip.com/downloads/en/DeviceDoc/doc8183.pdf | ATTINY84A-SSURCT-ND
10 |  | Badgelife_sao_connector_v169bis | X1 | Badgelife_sao_connector_v169bis | Badgelife-SAOv169-SAO-2x3_nopin1 | 1 |  | 732-5394-ND
Component Groups: | 10
Component Count: | 16
Fitted Components: | 16
Number of PCBs: | 1
Total components: | 16
Schematic Version: | v01
Schematic Date: | 2019-09-30
PCB Variant: | ['default']
BoM Date: | 10/25/2019 10:13:00 AM
Schematic Source: | C:\Users\sgmustadio\Documents\GitHub\avr-blink-badge\Hardware\wenk_sao\wenk_sao.sch
KiCad Version: | Eeschema (5.1.0)-1

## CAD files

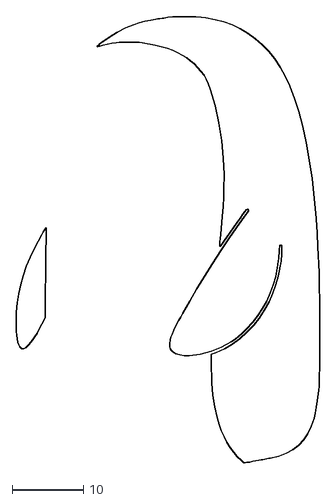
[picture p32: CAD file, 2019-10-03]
Images/gunter-outer.dxf
42.6 x 62.6

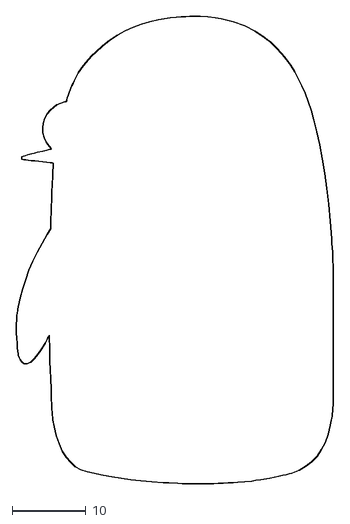
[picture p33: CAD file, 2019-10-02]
Images/gunter-outline.dxf
43.1 x 63.6

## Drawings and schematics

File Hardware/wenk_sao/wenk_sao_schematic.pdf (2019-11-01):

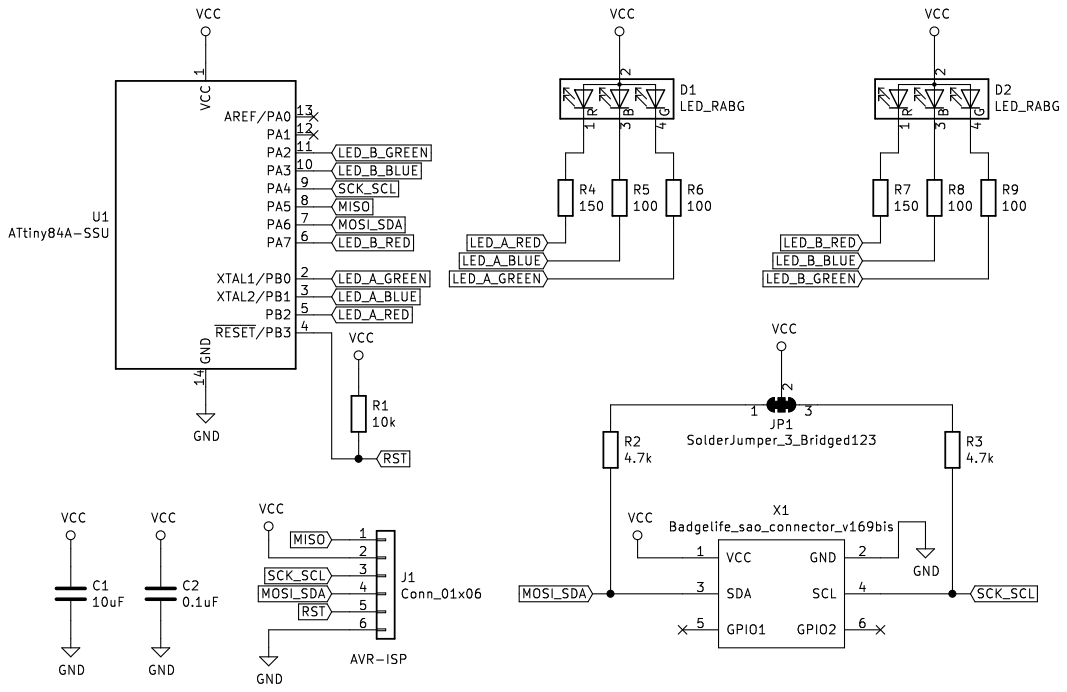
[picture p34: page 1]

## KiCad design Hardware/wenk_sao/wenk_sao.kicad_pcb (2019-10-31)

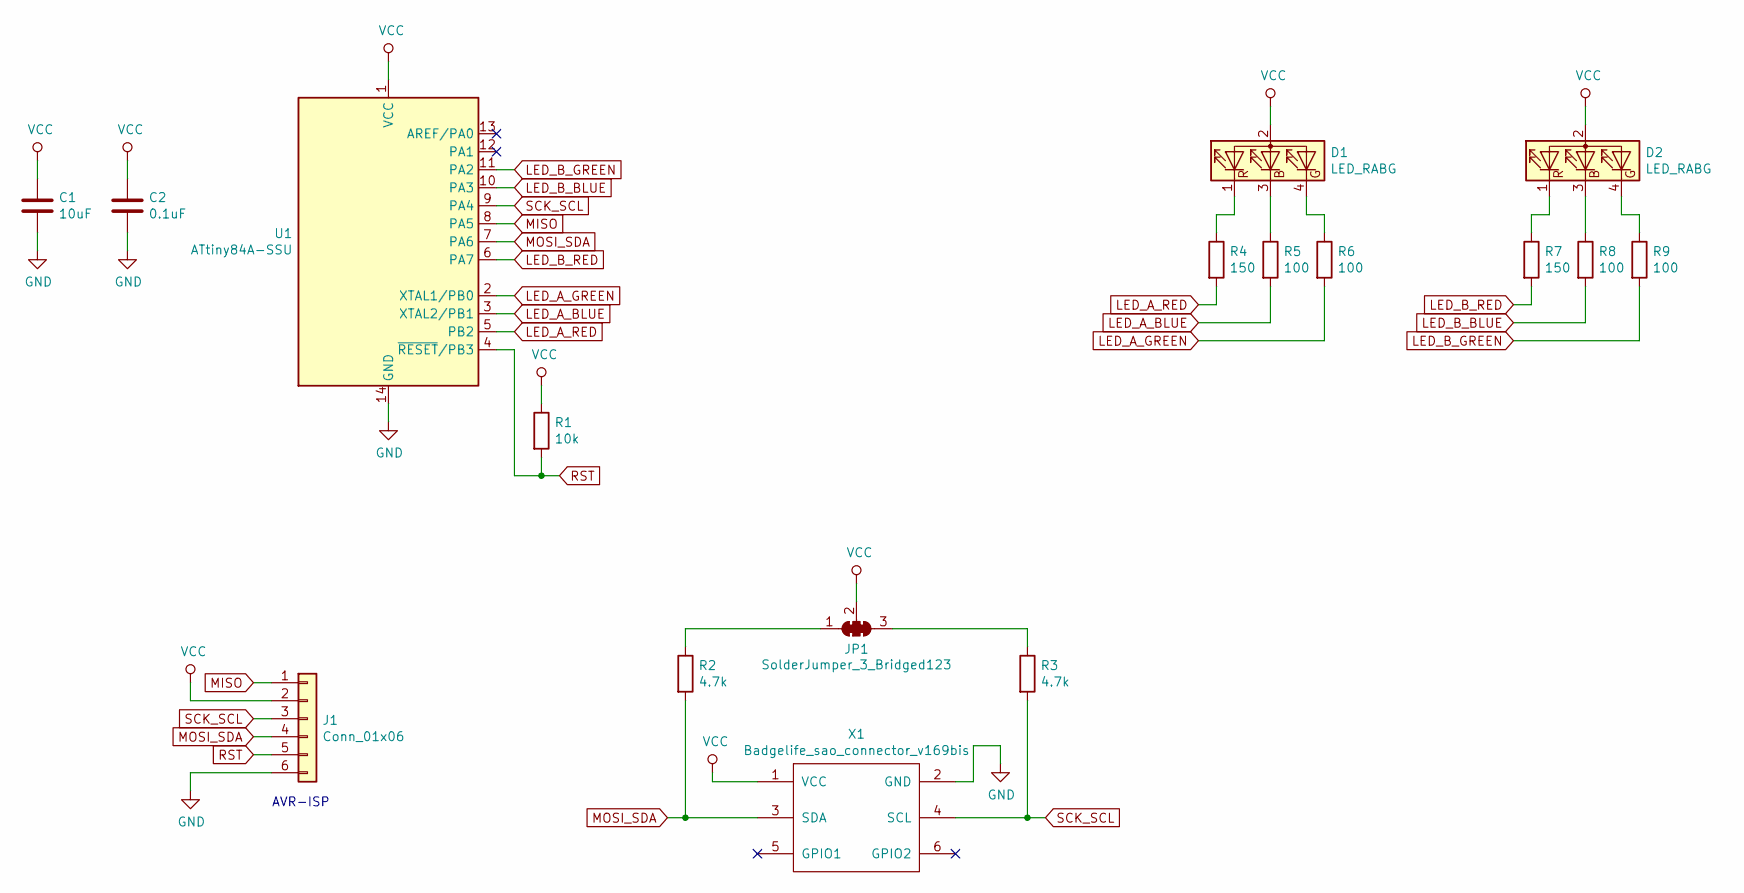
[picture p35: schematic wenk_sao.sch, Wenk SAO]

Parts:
C1: 10uF; C_0603_1608Metric; Digi-Key_PN 1276-1119-1-ND
C2: 0.1uF; C_0603_1608Metric; Digi-Key_PN 1276-1000-1-ND
D1, D2: LED_RABG; XZMDKCBDDG45S-9; Digi-Key_PN 1497-1257-1-ND
J1: Conn_01x06; Harwin_M20-89006xx_1x06_P2.54mm_Horizontal; Digi-Key_PN 952-3235-ND
JP1: SolderJumper_3_Bridged123; SolderJumper-3_P1.3mm_Bridged123_RoundedPad1.0x1.5mm
R1: 10k; R_0603_1608Metric; Digi-Key_PN 311-10.0KHRCT-ND
R2, R3: 4.7k; R_0603_1608Metric; Digi-Key_PN 311-4.70KHRCT-ND
R4, R7: 150; R_0603_1608Metric; Digi-Key_PN 311-150HRCT-ND
R5, R6, R8, R9: 100; R_0603_1608Metric; Digi-Key_PN 311-100HRCT-ND
U1: ATtiny84A-SSU; SOIC-14_3.9x8.7mm_P1.27mm; Digi-Key_PN ATTINY84A-SSURCT-ND
X1: Badgelife_sao_connector_v169bis; Badgelife-SAOv169-SAO-2x3_nopin1; Digi-Key_PN 732-5394-ND

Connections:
GND: C1.2, C2.2, J1.6, U1.14 (GND), X1.2 (GND)
LED_A_BLUE: R5.2, U1.3 (XTAL2/PB1)
LED_A_GREEN: R6.2, U1.2 (XTAL1/PB0)
LED_A_RED: R4.2, U1.5 (PB2)
LED_B_BLUE: R8.2, U1.10 (PA3)
LED_B_GREEN: R9.2, U1.11 (PA2)
LED_B_RED: R7.2, U1.6 (PA7)
MISO: J1.1, U1.8 (PA5)
MOSI_SDA: J1.4, R2.2, U1.7 (PA6), X1.3 (SDA)
unnamed: D1.1 (RK), R4.1
unnamed: D1.3 (BK), R5.1
unnamed: D1.4 (GK), R6.1
unnamed: D2.1 (RK), R7.1
unnamed: D2.3 (BK), R8.1
unnamed: D2.4 (GK), R9.1
unnamed: JP1.1 (A), R2.1
unnamed: JP1.3 (B), R3.1
RST: J1.5, R1.2, U1.4 (~RESET~/PB3)
SCK_SCL: J1.3, R3.2, U1.9 (PA4), X1.4 (SCL)
VCC: C1.1, C2.1, D1.2 (A), D2.2 (A), J1.2, JP1.2 (C), R1.1, U1.1 (VCC), X1.1 (VCC)

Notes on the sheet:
AVR-ISP

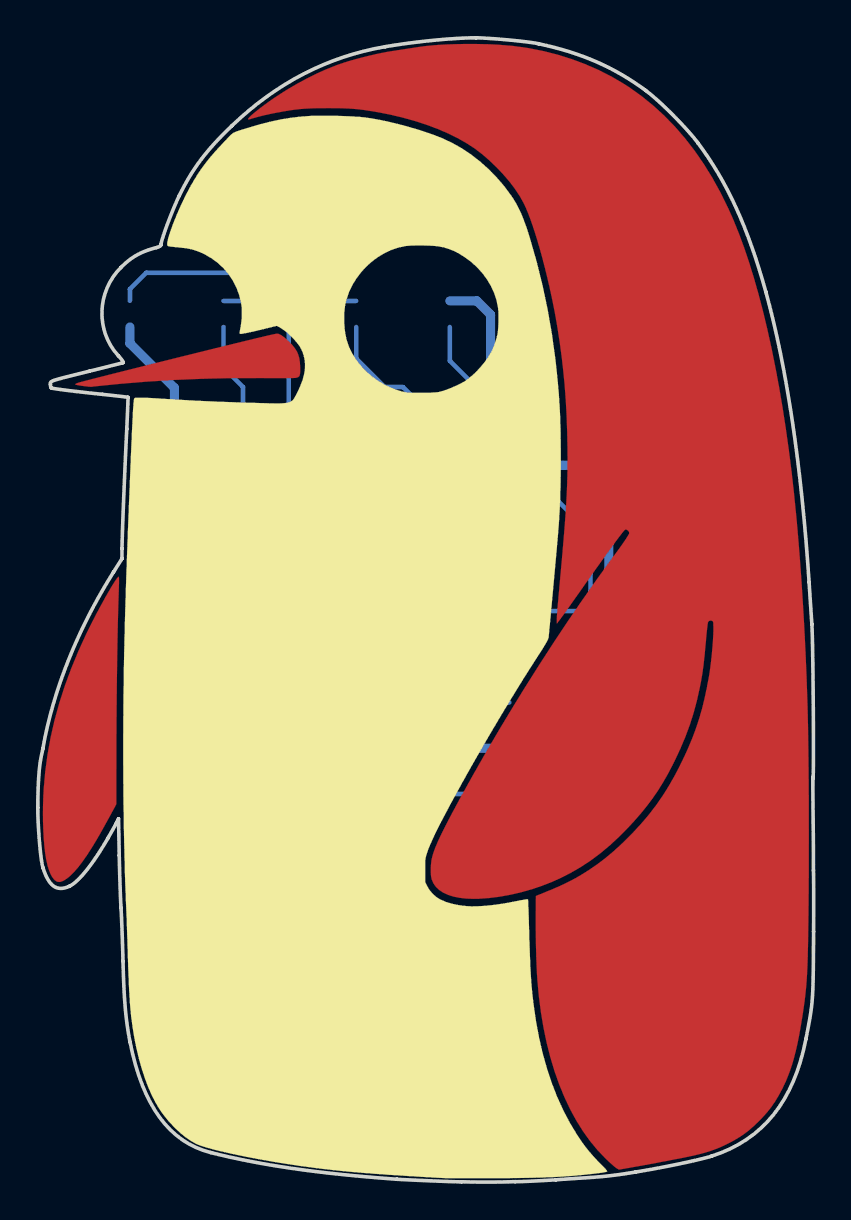
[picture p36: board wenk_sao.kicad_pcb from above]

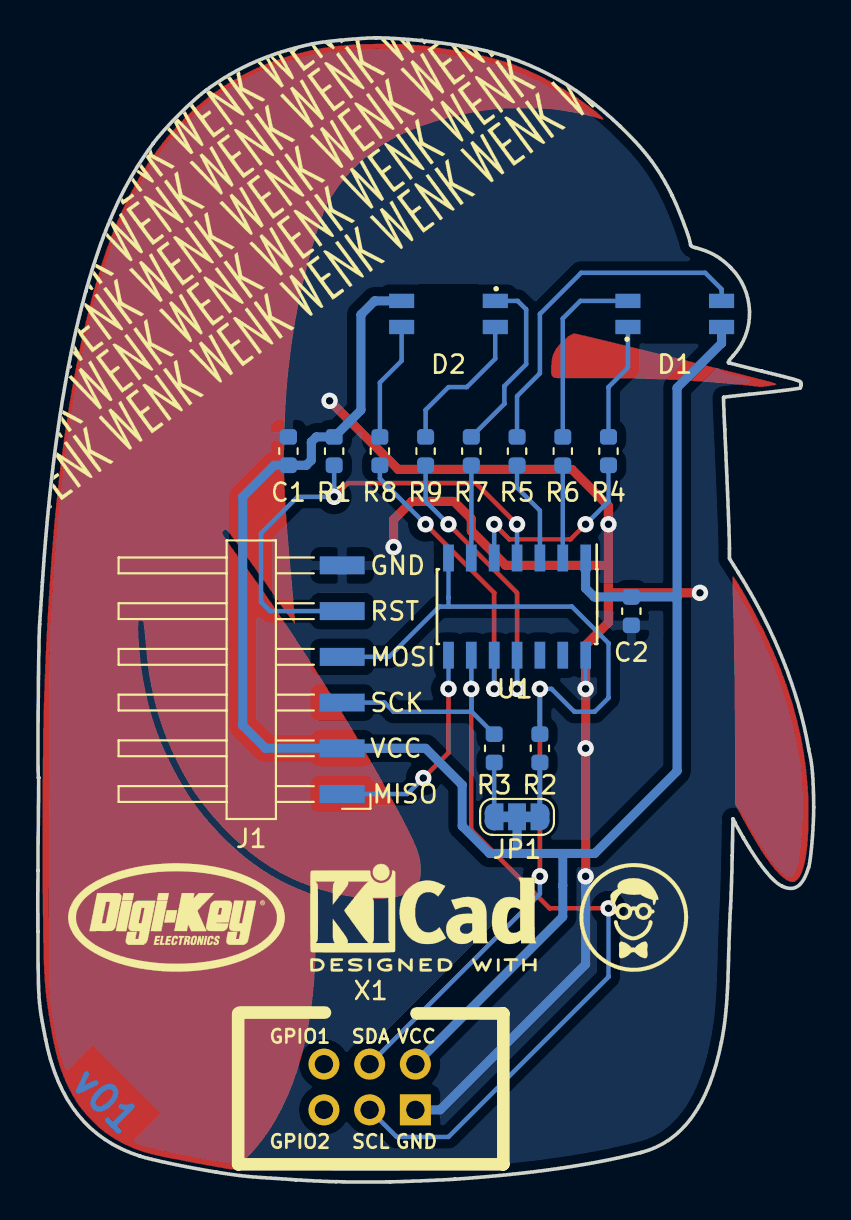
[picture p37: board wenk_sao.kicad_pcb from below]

Board: 2 copper layers, 43.1 x 63.6 mm, 17 parts (16 on the bottom side), 20 nets.

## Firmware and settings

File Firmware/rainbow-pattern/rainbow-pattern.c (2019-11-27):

/**
 * Title: Rainbow Pattern
 * Author: Shawn Hymel
 * Date: November 2, 2011
 *
 * Create a rainbow pattern on the eyes of the Wenk SAO board.
 * Compiled for ATtiny84A.
 * 
 * Note: You will need to remove the internal clock divider (div 8) fuse to make
 *       the LEDs appear steady. Use the following:
 *          $ avrdude -c usbtiny -p t84 -U lfuse:w:0xE2:m
 *
 * Beerware: As long as you retain this notice you
 * can do whatever you want with this stuff. If we meet some day, and you think
 * this stuff is worth it, you can buy me a beer in return.
 */

// Need to define clock speed for delay functions
#ifndef F_CPU
#define F_CPU 8000000UL // 8 MHz clock speed
#endif

#include <avr/io.h>
#include <avr/interrupt.h>
#include <util/delay.h>

// Function declarations
void leftWheel(uint8_t wheel_pos);
void rightWheel(uint8_t wheel_pos);

// Rainbow offset
const uint8_t left_offset = 40;
const uint8_t right_offset = 0;

// Timer values
const uint8_t t0_load = 0;
const uint8_t t0_comp = 65; // ~60 Hz PWM

// LED pins (left = PORTB, right = PORTA)
const uint8_t p_lr = 2;
const uint8_t p_lg = 0;
const uint8_t p_lb = 1;
const uint8_t p_rr = 7;
const uint8_t p_rg = 2;
const uint8_t p_rb = 3;

// Tick counter
volatile uint8_t ticks = 0;

// Duty cycle per color
volatile uint8_t left_r = 0;
volatile uint8_t left_g = 0;
volatile uint8_t left_b = 0;
volatile uint8_t right_r = 0;
volatile uint8_t right_g = 0;
volatile uint8_t right_b = 0;

// Program entry point
int main(void) {
    
    // Make LED pins output
    DDRA = (1 << p_rr) | (1 << p_rg) | (1 << p_rb);
    DDRB = (1 << p_lr) | (1 << p_lg) | (1 << p_lb);
    
    // Set Timer 0 to normal operation
    TCCR0A = 0;
    TCCR0B = 0;
    
    // Set prescaler to 8
    TCCR0B |= (1 << CS01);
    
    // Reset Timer 0 and set compare values
    TCNT0 = t0_load;
    OCR0A = t0_comp;
    
    // Enable Timer 0 compare interrupt
    TIMSK0 = (1 << OCIE0A);
    
    // Enable global interrupts
    sei();
    
    // Infinite loop
    while(1) {
        for ( uint16_t i = 0; i < 256; i++ ) {
            leftWheel((i + left_offset) % 255);
            rightWheel((i + right_offset) % 255);
            _delay_ms(10);
        }
    }
}

// Set left eye to color based on input wheel position (0..255)
// Based on https://codebender.cc/sketch:80438#Neopixel%20Rainbow.ino
void leftWheel(uint8_t wheel_pos) {
    if ( wheel_pos < 85 ) {
        left_r = wheel_pos * 3;
        left_g = 255 - (wheel_pos * 3);
        left_b = 0;
    } else if ( wheel_pos < 170 ) {
        wheel_pos -= 85;
        left_r = 255 - (wheel_pos * 3);
        left_g = 0;
        left_b = wheel_pos * 3;
    } else{
        wheel_pos -= 170;
        left_r = 0;
        left_g = wheel_pos * 3;
        left_b = 255 - (wheel_pos * 3);
    }
}

// Set right eye to color based on input wheel position (0..255)
// Based on https://codebender.cc/sketch:80438#Neopixel%20Rainbow.ino
void rightWheel(uint8_t wheel_pos) {
    if ( wheel_pos < 85 ) {
        right_r = wheel_pos * 3;
        right_g = 255 - (wheel_pos * 3);
        right_b = 0;
    } else if ( wheel_pos < 170 ) {
        wheel_pos -= 85;
        right_r = 255 - (wheel_pos * 3);
        right_g = 0;
        right_b = wheel_pos * 3;
    } else{
        wheel_pos -= 170;
        right_r = 0;
        right_g = wheel_pos * 3;
        right_b = 255 - (wheel_pos * 3);
    }
}

// Interrupt service routine
ISR(TIM0_COMPA_vect) {
    
    // Reset Timer 0
    TCNT0 = t0_load;
    
    // Increment counter (just let roll over)
    ticks++;
    
    // Save ticks to local variable to save RAM lookup cycles
    uint8_t t = ticks;
    
    // Set left LED based on duty cycle
    if ( t < left_r ) {
        PORTB &= ~(1 << p_lr); // LED on
    } else {
        PORTB |= (1 << p_lr);  // LED off
    }
    if ( t < left_g ) {
        PORTB &= ~(1 << p_lg); // LED on
    } else {
        PORTB |= (1 << p_lg);  // LED off
    }
    if ( t < left_b ) {
        PORTB &= ~(1 << p_lb); // LED on
    } else {
        PORTB |= (1 << p_lb);  // LED off
    }
    
    // Set right LED based on duty cycle
    if ( t < right_r ) {
        PORTA &= ~(1 << p_rr); // LED on
    } else {
        PORTA |= (1 << p_rr);  // LED off
    }
    if ( t < right_g ) {
        PORTA &= ~(1 << p_rg); // LED on
    } else {
        PORTA |= (1 << p_rg);  // LED off
    }
    if ( t < right_b ) {
        PORTA &= ~(1 << p_rb); // LED on
    } else {
        PORTA |= (1 << p_rb);  // LED off
    }
}

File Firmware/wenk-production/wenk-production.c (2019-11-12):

#ifndef F_CPU
#define F_CPU 1000000UL // 1 MHz clock speed
#endif

#include <avr/io.h>
#include <util/delay.h>

int main(void) {
    
    // Make PA2/3/7 and PB0/1/2 output
    DDRA |= 0b10001100;
    DDRB |= 0b00000111;
    
    // Turn off LEDs by default
    PORTA |= 0b10001100;
    PORTB |= 0b00000111;
    
    // Flash through colors a few times
    for ( uint8_t i = 0; i < 3; i++ ) {
        
        // Turn off blue
        PORTA |= (1 << 3);
        PORTB |= (1 << 1);
        
        // Turn on red
        PORTA &= ~(1 << 7);
        PORTB &= ~(1 << 2);
        _delay_ms(500);
        
        // Turn off red
        PORTA |= (1 << 7);
        PORTB |= (1 << 2);
        
        // Turn on green
        PORTA &= ~(1 << 2);
        PORTB &= ~(1 << 0);
        _delay_ms(500);
        
        // Turn off green
        PORTA |= (1 << 2);
        PORTB |= (1 << 0);
        
        // Turn on blue
        PORTA &= ~(1 << 3);
        PORTB &= ~(1 << 1);
        _delay_ms(500);
    }
    
    // Turn on all (white)
    PORTA &= ~((1 << 7) | (1 << 2) | (1 << 3));
    PORTB &= ~((1 << 2) | (1 << 0) | (1 << 1));
    
    // Do nothing
    while (1);
}

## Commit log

2019-10-02 Schematic done. Part placement done. Test board outline import done.
    [gunter-outline.dxf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]
2019-10-03 Gunter art layers done!
    [gunter-outer.dxf, supercon-2019-blink.kicad_pcb, supercon-2019-blink.sch]
2019-10-04 v01 PCB layout complete
    [supercon-2019-blink-B_Cu.gbr, supercon-2019-blink-B_Mask.gbr, supercon-2019-blink-B_Paste.gbr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]
2019-10-08 Added silk labels to ISP header
    [supercon-2019-blink-B_Cu.gbr, supercon-2019-blink-B_Mask.gbr, supercon-2019-blink-B_Paste.gbr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]
2019-10-31 Added production test firmware
    [wenk_sao-B_Cu.gbr, wenk_sao-B_Mask.gbr, wenk_sao-B_Paste.gbr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]
2019-11-01 Added exercises and python uploader script
    [wenk_sao.sch]
2019-11-02 Added software PWM example and rainbow example
2019-11-02 Added images
    [programmer-hookup.fzz]
2019-11-12 Updated worksheet
    [wenk_sao_jig.kicad_pcb, wenk_sao_jig.sch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]
